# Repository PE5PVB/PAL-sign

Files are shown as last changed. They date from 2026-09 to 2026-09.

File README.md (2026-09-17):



# PAL-sign
Advanced CVBS PAL test card generator, built around an RP2350 and an ADV7391 video encoder

A standalone hardware test card generator for anyone working with analogue television: an ATV contest, aligning a transmitter or receiver, or just needing a proper PAL B/G composite signal on the bench. Twenty broadcast-standard test cards, generated in real time and sent out as CVBS, no PC required to run it.

## Features
- Twenty built-in test cards: PM5644 (4:3 and 16:9), BBC Cards F/G/W, FuBK (full, simple and 16:9), EBU colour bars and black & white, Crosshatch, Multiburst, Pulse & Bar, sin(x)/x, Mixed bars, Picdream, an ATV Contest card and a TVE card
- Fourteen Custom slots for your own pictures, uploaded from the PC tool
- BBC Test Card F and W can each show a photo of your own instead of the original, centred and uploaded from the PC tool
- Teletext, WSS aspect ratio signalling and Insertion Test Signal (ITS) support
- A slideshow with a fade between pictures
- A scrolling ticker band, colour, speed and size configurable per card
- An on-device menu on its own screen, driven by a rotary encoder, so every setting is reachable without a PC
- Optional PCM audio: with a PCM1808 ADC attached, two extra cards embed stereo sound in the picture itself (see "PCM audio" below)
- A Windows configurator to upload your own pictures and change every setting from a PC

## Controls and settings
Everything below is reachable from the on-device screen and knob, or from the PC tool; the two show the same settings.

### The screen and the knob
A small screen and a rotary encoder on the front, entirely optional: unplug that panel and the firmware skips it and keeps generating video (a pin on the flatcable tells it whether the panel is there). Turning the knob steps through the list of cards without touching what is on air; pushing switches to the highlighted one.
- A short press opens a menu for the card currently shown, with everything specific to that one card.
- A press held for about two seconds opens the System menu instead, with everything that is not tied to one card.
- The menu closes itself after a minute of no input.
- Holding the knob down while powering the board on starts a five-second on-screen countdown; holding through the whole countdown runs a full factory reset (every setting back to its default) once it finishes, releasing early cancels it.

### The per-card menu (short press)
What is offered depends on the card: one with no room for a ticker will not offer one, and one with no clock box will not offer a colour for it. Between them, the twenty cards can offer:
- Enabled: whether stepping through the cards can land on this one; a disabled card keeps its settings, it is just skipped
- Ticker: off, solid or transparent (transparent only on a built-in card, an uploaded photo has no room budget for it), its vertical position, speed and direction, one of five sizes and four fonts, and its colour
- Aspect ratio: nine WSS modes, off, 4:3 full frame, 14:9 letterbox (centred or at the top), 14:9 full frame, 16:9 letterbox (centred or at the top), 16:9 anamorphic, and a wider-than-16:9 letterbox, switching the ADV7391's own wide screen signalling to match
- The first and second identification lines: shown or hidden, and their own colour
- The moving line, on the cards that have one
- The insert boxes (a running clock, or fixed text instead): off, time only, date and time, or the fixed text
- The text font used for all of the above
- A handful of card-specific extras: the PM5644 16:9's chroma test bars, Test Card G's AP2 variant, the ATV Contest card's two lines and contest number, and BBC Test Card F/W's own switch for a custom photo instead of the original

### The System menu (long press)
- Text: the first and second identification line, the ticker message, and the fixed text an insert box shows instead of a running clock
- Switches: teletext, ITS (Insertion Test Signal), VBI, and automatic summer time
- Two cycles: the ADV7391's luma and chroma filter presets
- The screen's own brightness
- The date and time, set field by field, kept automatically in step with summer time if that switch is on
- Enabling or disabling any of the twenty cards, without touching what is currently on air
- Seven analogue controls on the ADV7391 itself: DAC gain, Y scale, brightness, hue, the luma peaking filter (SSAF), and the luma and chroma delay

### The slideshow
A sequence of steps, each "how long, which card", built by dragging cards into an order in the PC tool. Any card can appear more than once, each occurrence with its own duration, and there is an optional fade between pictures. The sequence is stored in its own flash page and survives a power cycle, so a slideshow left running keeps running after a restart.

### The ticker
A scrolling text band that can run on almost any card, configured per card as listed above: on or off, or transparent over the picture instead of a solid band; where it sits, how fast and in which direction it scrolls; one of five sizes, one of four fonts, and its own colour. The message itself is shared across every card that shows it.

### Your own photo on BBC Test Card F and W
Both cards have their own oval photo window built in; the PC tool's "Upload portrait..." button lets you put your own picture there instead. The two windows are not quite the same size or shape, so one upload feeds both: choose a photo, drag it and use the zoom slider until the right part sits inside both outlines shown on the preview, and both are cut out and sent in one step. Each card keeps its own on/off switch (see the per-card menu above), so you can show your photo on one, the original on the other, or either everywhere.

## Test cards
Six of the twenty, captured straight off the composite output.

<table>
<tr>
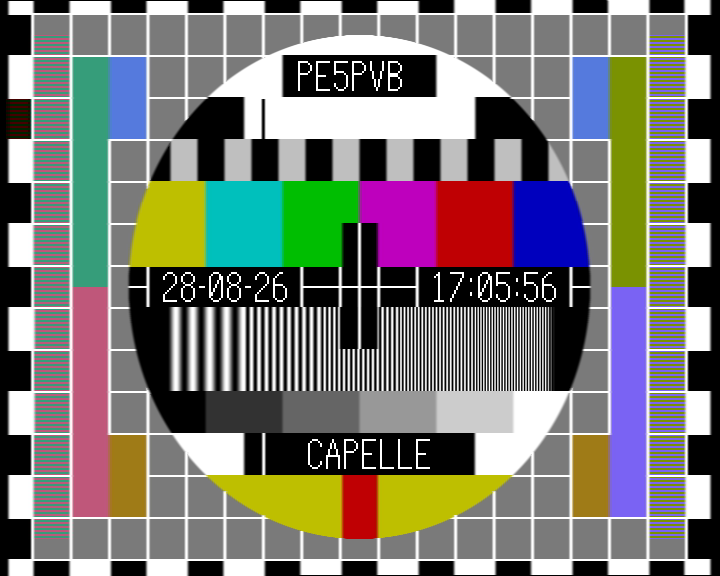
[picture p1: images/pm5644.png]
PM5644
<td width="33%"><br><b>PM5644</b><br>The classic Philips PM5644, straight from the original EPROM dump: colour bars, a resolution grating in each corner, a grey scale and the two identification boxes, "PE5PVB" and "CAPELLE" here, with the on-device clock in the middle.</td>
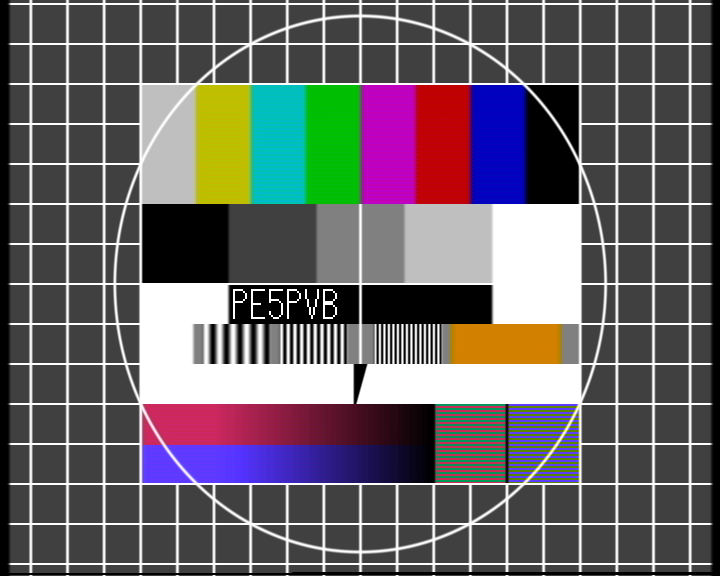
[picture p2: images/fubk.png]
FuBK
<td width="33%"><br><b>FuBK</b><br>FuBK, the German counterpart of the PM5544, taken from an actual composite recording. The two striped fields right of the gradient bars deliberately mis-modulate the colour signal; a properly working PAL decoder averages them down to plain grey.</td>
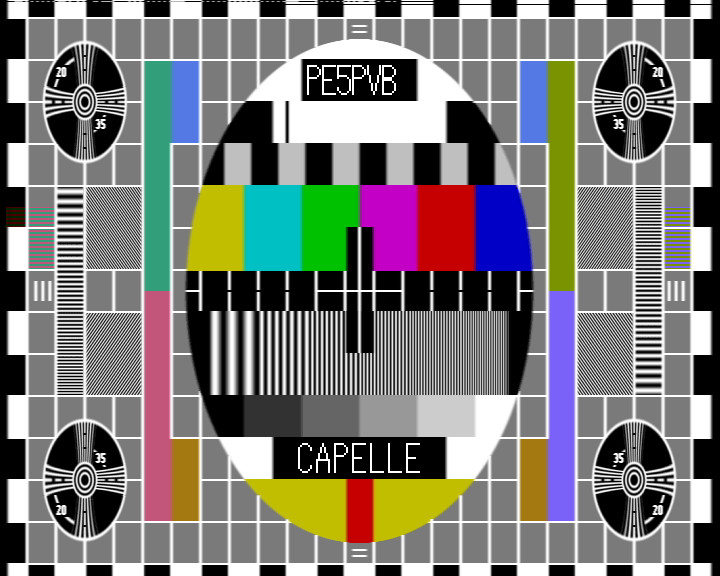
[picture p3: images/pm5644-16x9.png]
PM5644 16:9
<td width="33%"><br><b>PM5644 16:9</b><br>The same PM5644 picture from a newer generation of the encoder EPROM (G924): finer detail and the identification boxes in slightly different places than the plain PM5644.</td>
</tr>
<tr>
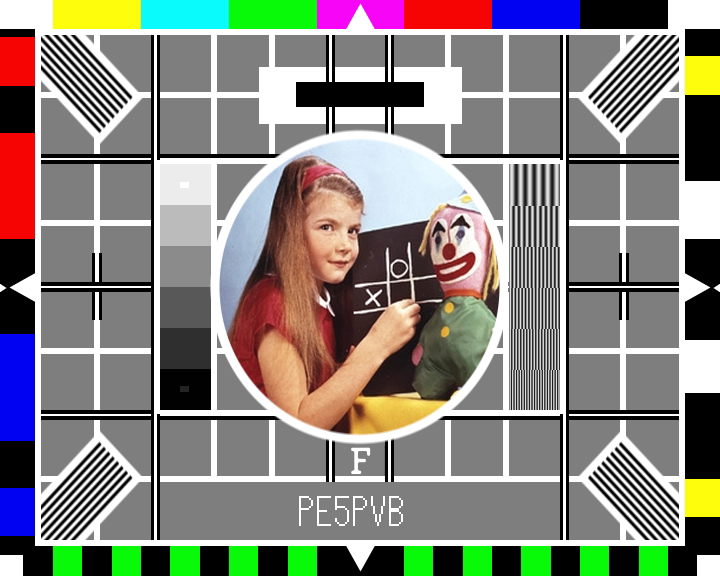
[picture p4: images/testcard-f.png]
BBC Test Card F
<td width="33%"><br><b>BBC Test Card F</b><br>The well known girl-and-clown card, rebuilt from the original photo scan, surrounded by colour bars, resolution wedges and a grey scale.</td>
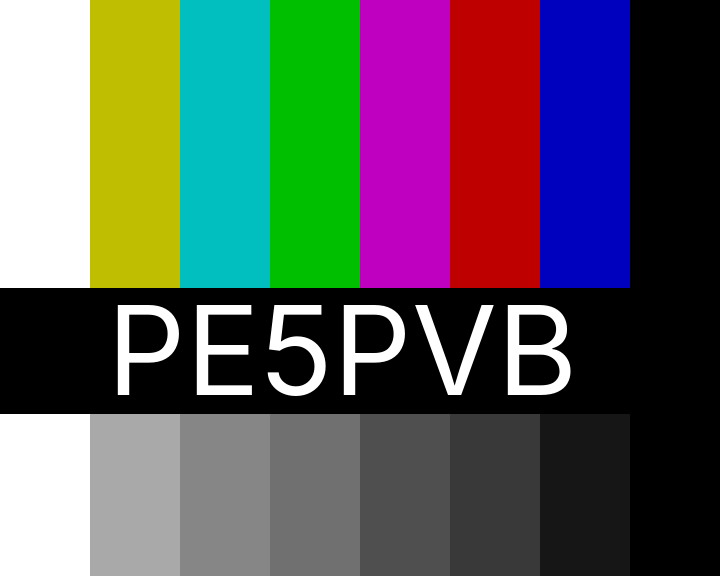
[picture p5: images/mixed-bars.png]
Mixed bars
<td width="33%"><br><b>Mixed bars</b><br>The same eight colour bars twice: once in colour, once with the chroma stripped out, so the bottom row shows exactly the brightness each colour bar carries.</td>
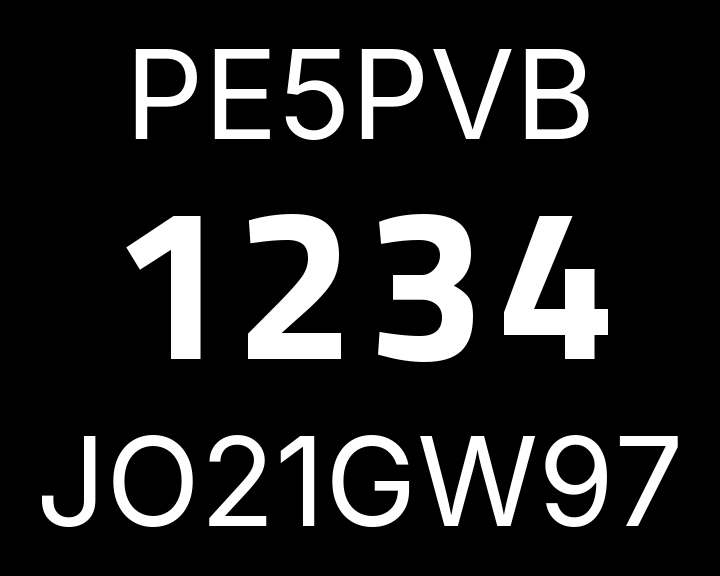
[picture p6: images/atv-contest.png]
ATV Contest
<td width="33%"><br><b>ATV Contest</b><br>Callsign, contest number and locator in large, legible digits, meant to be read off a weak or noisy signal during a contest.</td>
</tr>
</table>

## How it works

### From pixels to composite video
The RP2350 does not generate the analogue PAL signal itself. Its PIO hardware (a handful of small, exactly timed state machines built into the chip for jobs like this) pushes the picture out as a digital YCbCr 4:2:2 byte stream on an 8 bit bus, together with a 27 MHz clock, following the BT.656 standard. That digital stream, plus a couple of control pins, goes straight into an Analog Devices ADV7391 video encoder over I2C for configuration. The ADV7391 does the actual PAL encoding: it generates the colour subcarrier, mixes in luma and chroma, adds the analogue sync pulses and drives the composite (CVBS) output.

### No separate sync wires
An older-style video source uses two extra wires next to the picture data, HSYNC and VSYNC, to mark the start of every line and every field. BT.656 does not need them: it puts special byte codes (SAV and EAV, values that never occur in real picture data) straight into the byte stream itself, at the start and end of every active line. The ADV7391 reads its own timing out of those codes, so on this board HSYNC and VSYNC are simply wired high and never toggle.

### Keeping the two cores in step
One RP2350 core works out the pixel data for the current picture, line by line, and writes it into a ring buffer. The other core only reads that buffer back out to the PIO/DMA hardware, at a fixed pace, so the picture can never fall behind: DMA moves the bytes from the buffer into the PIO's FIFO without either core handling them one by one. If the rendering core ever gets too far behind, for instance during a picture switch, the firmware notices and falls back to repeating the last complete picture instead of letting anything incomplete reach the screen.

### Teletext, WSS and the other things hidden in the picture
Teletext, the widescreen signalling (WSS) and the insertion test signal (ITS) are not produced by a separate chip. They are ordinary picture data: a handful of lines in the vertical blanking interval, the lines you never actually see, above and below the visible picture, get filled with luma samples that decode into the teletext bits or the WSS code, exactly like any other line of picture content decodes into a colour. The firmware works out that waveform itself, pulse by pulse, to the shape the relevant standard requires, and writes it straight into the same buffer the ADV7391 streams out.

### Test cards and your own pictures
The twenty built-in test cards are pixel data compiled straight into the firmware; several of them, the PM5644 and BBC cards, come from the original EPROM dumps of real broadcast test card generators. Alongside those sit fourteen Custom slots: plain picture data reserved in the last part of the 16 MB flash chip, which you fill from the PC tool over the same USB serial connection used for firmware uploads.

### The screen and the knob
The screen on the front is a plain SPI display, and the knob next to it is an ordinary quadrature rotary encoder, decoded from a GPIO interrupt so a fast turn is never missed; see "Controls and settings" above for what they do.

## Connecting the screen and the knob
The screen and the rotary encoder live on their own small front panel PCB, connected with a flatcable, and the whole panel is optional: one pin on the cable tells the firmware whether it is there, and without it the board runs headless and keeps generating video.

The display is an **ST7789P3** SPI panel of **76 x 284 pixels** (a window inside the controller's 240 x 320 frame memory), driven over SPI0. The knob is an ordinary quadrature rotary encoder with a push switch; the RP2350's internal pull-ups do the rest, so the panel needs no resistors or capacitors of its own.

| Signal | GPIO | Notes |
|---|---|---|
| Display RST | GP19 | |
| Display CS | GP20 | |
| Display DC | GP21 | low = command |
| Display SCK | GP22 | SPI0 SCK |
| Display MOSI (SDA) | GP23 | SPI0 TX |
| Display backlight | GP26 | active high |
| Panel present | GP24 | tie to GND on the panel |
| Encoder phase A | GP27 | internal pull-up |
| Encoder phase B | GP28 | internal pull-up |
| Encoder push | GP29 | internal pull-up |

Plus 3.3 V and GND for the panel itself. The encoder's common and the switch's other side go to GND.

## PCM audio
An optional PCM1808 audio ADC turns the generator into a video-plus-audio source: the analogue stereo input is sampled at 48 kHz and embedded in the picture itself as data lines, in the spirit of the PCM adaptors of the early digital audio era. Two extra cards carry it:

- **Ham PCM**: an own format designed for FM ATV links, with Reed-Solomon error protection, a small text channel, and four quality modes: HQ (48 kHz, 14 bit stereo), LQ (32 kHz, 12 bit stereo), Voice (32 kHz A-law) and Narrow (16 kHz mono A-law).
- **Sony PCM**: a Sony/EIAJ STC-007-compatible signal (44.1 kHz, 14 or 16 bit, selectable pre-emphasis) that period PCM adaptors and third-party software decoders understand.

Both cards appear automatically when the ADC is detected at power-on, and stay completely hidden without it, on the board, in the menu and in the PC tool alike. The `PcmDecoder` tool in `PC Software/` plays the audio back on a PC from a composite capture card, with a live view of the decode quality.

The ADC connects over I2S, with the PCM1808 in master mode: the board supplies only the 12.288 MHz system clock, and the ADC generates its own bit and word clocks from it.

| Signal | GPIO | Direction |
|---|---|---|
| SCKI (256 fs master clock) | GP13 | board to ADC |
| BCK (bit clock) | GP9 | ADC to board |
| LRCK (word clock) | GP10 | ADC to board |
| DOUT (I2S data) | GP11 | ADC to board |

Plus supply and GND for the ADC board. The PCM1808's mode pins go high for master mode (MD1 = MD0 = high).

## Repository layout
- `Firmware/` -- the firmware for the RP2350, built with PlatformIO or the Arduino IDE
- `PC Software/` -- the Windows configurator, see [its own README](PC%20Software/README.md) for how to build and use it
- `Hardware/Kicad/` -- the PCB design

## Building the firmware
```
cd Firmware
pio run
pio run -t upload
```
PlatformIO picks up everything it needs from `platformio.ini`, including the board profile for the bare RP2350. Opening `Firmware.ino` in the Arduino IDE (2.x) works as well; `sketch.yaml` carries the same board settings.

## Contributing
Found a bug or have an idea? Open an [issue](https://github.com/PE5PVB/PAL-sign/issues) or a [pull request](https://github.com/PE5PVB/PAL-sign/pulls), I will review it and merge into main. Since this project is dual-licensed (see below), a pull request means you agree that your contribution is licensed the same way as the rest of the project, under both the GPLv3 and the commercial license.

## License
This project is dual-licensed.

You may use it under the terms of the GNU General Public License, either version 3 of the License, or (at your option) any later version: this program is free software, you can redistribute it and/or modify it under those terms. It is distributed in the hope that it will be useful, but WITHOUT ANY WARRANTY; without even the implied warranty of MERCHANTABILITY or FITNESS FOR A PARTICULAR PURPOSE. See the [LICENSE](LICENSE) file for the full text.

If the GPLv3's terms do not suit your use, for example because you want to use this project, or a part of it, in a closed-source or commercial product without releasing your own source code, a separate commercial license is available. See [pe5pvb.nl](https://www.pe5pvb.nl/) for contact details.

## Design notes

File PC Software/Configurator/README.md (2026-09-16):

# PAL-sign, the configurator

Windows program that goes with the test card generator. Its sibling
`../PCMDecoder` (same folder layout) turns a captured Ham PCM or Sony
PCM picture back into sound; `../PAL-sign.sln` opens both projects in
Visual Studio 2022 or newer. From the command line:

```
dotnet run --project src/PAL-sign.csproj
```

A standalone .exe (needs the .NET 8 Desktop runtime) is built by
`publish.bat`. Use that script rather than a hand written
`dotnet publish`: the options interact in a way that is easy to get wrong
on the command line.

C# on .NET 8 (LTS) with WinForms, three tab pages: Cards (every per-card
setting, including converting a photo and sending it to one of the
fourteen Custom slots, or a photo of your own onto BBC Test Card F/W's
own oval window), Slideshow, and System (everything that is not tied to
one card).

## The risk of this program, and how it is covered

This is the **second implementation** of the image conversion. The first
is in `../../Firmware/tools/convert_image.py` and is the one proven to work
on the board. Two implementations drift apart sooner or later, and then a
difference on the screen can no longer be traced back to one cause.

That is why it has been made measurable instead of hoped for:

```
python compare.py
```

That runs both implementations on the same input and lays the output side
by side byte for byte, in two trials with a different purpose:

**A. The arithmetic.** Input that is already 720x576, so nothing is
scaled. What is left is the YCbCr conversion, the flicker filter, the
chroma halving and the level limiting. That ought to be equal byte for
byte, and it is, at flicker filter 0.00, 0.50 and 1.00. If this differs,
there is a real fault.

**B. The scaling.** No equality is expected here: PIL works out its
Lanczos weights in fixed point and rounds per pass to 8 bits, the C#
version works in double. What the trial reports is the size of the
difference, so that you can tell rounding noise from something else.

That second trial paid for itself immediately. It found that
`DrawImageUnscaled` from GDI+ scales to the **physical** size and not
pixel for pixel: a JPEG of 72 dpi was enlarged by 96/72 before the tool's
own Lanczos had even started, which is not recognisable as a fault by
eye. See the explanation in `src/ImageReader.cs`.

**Before either trial**, `compare.py` checks `ImageConvert.AlgoVersion`
(read straight from the built exe, `PAL-sign.exe --algo-version`)
against `ALGO_VERSION` in `convert_image.py`, and stops right there if
they differ. A byte-for-byte pass in trial A only proves the two are
still the same algorithm if this matched first: without it, a change on
one side that happens to still pass on whatever input trial A used that
day would go unnoticed. Whoever changes the pixel arithmetic on either
side bumps both constants, in the same commit, once trial A passes
again.

## Checking the layout

```
src/bin/Debug/net8.0-windows/PAL-sign.exe --layout layout.txt
```

Builds the window off screen, lets it lay itself out, and writes down
where every element ends up. It reports two things you spot too late by
eye: elements that **overlap each other** and elements that fall
**outside their parent**. Exit code 0 means clean.

With WinForms the order of `Controls.Add` determines who takes precedence
when docking, and an element set to `Fill` that is added **first** claims
the whole client area, leaving the rest to end up on top of it. That is
why everything now sits in a `TableLayoutPanel`.

## What the settings do

| | |
|---|---|
| **To** | which of the fourteen uploadable Custom slots you overwrite |
| **Crop** | fill the picture instead of black bars |
| **Force square-pixel scaling on an exact 720x576 source** | scale it anyway, instead of passing it through as already PAL-shaped |
| **Flicker filter** | takes the interlace twitter out; see below |

### Flicker filter

Even image rows go to field 1 and odd ones to field 2. Anything that
changes sign from row to row, a roof edge, a striped shirt, a horizontal
branch, therefore sits differently in one field than in the other, and
you see that as flicker at 25 Hz.

The kernel `[1,2,1]/4` is derived and not chosen: it is exactly the
filter that sets that alternating component to zero. See `AntiTwitter()`
in `src/ImageConvert.cs` and `anti_twitter()` in `convert_image.py`.

At 1.00 the twitter is fully gone. It costs vertical sharpness, because
the twittering component is vertical detail; at 0.50 you leave half of it
standing.

## The preview

What you see is not the bare 720x576 raster but the picture **stretched
to 4:3**, because that is how it arrives on the television. It is also
worked back out of the actual 4:2:2 bytes, so you see what the chroma
halving and the level limiting make of it as well.

## During the upload

**No picture** comes out of the board while it is writing. The board does
**not** restart and the port simply stays open: the streamer on the other
core runs from RAM and keeps sending blank lines with correct sync. The
explanation is at `photoUpload()` in `../../Firmware/src/main.cpp`.

At the end the firmware reports the CRC it has read back out of the
**flash**, and the configurator compares that with its own calculation.
If it says "CRC agrees", then it really is in there correctly.

## The command line remains

`../../Firmware/tools/convert_image.py` still does the same thing and is the
reference that `compare.py` measures against. There was also a tkinter
window; that lapsed when this program arrived.

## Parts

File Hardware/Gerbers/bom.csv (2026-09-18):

Designator | Footprint | Quantity | Value | LCSC Part #
BT1 | CR2032-BS-6-1 | 1 | ML2032 | C70377
C1, C2, C5, C6, C9 | 0603 | 5 | 4.7uF | C19666
C10, C12, C13, C14, C15, C16, C17, C18, C19, C20, C21, C22, C25, C28, C32, C34, C35, C37, C39, C42, C44, C45, C47, C7, C8 | 0603 | 25 | 100n | C14663
C11 | 0603 | 1 | 4n7 | C53987
C23, C38, C43, C46 | 0603 | 4 | 10uF | C96446
C24, C27 | 0603 | 2 | 10n | C57112
C26 | 0603 | 1 | 2.2nF | C1604
C29 | 0603 | 1 | 150n | C513735
C3, C4 | 0603 | 2 | 15p | C1644
C30 | 0603 | 1 | 12n | C107074
C31, C33, C36 | CP_Elec_8x10 | 3 | 470uF | C48970894
C40, C41 | 0805 | 2 | 22uF | C45783
D1, D6 | D_SOD-123 | 2 | B5819W | C8598
D2 | 0603 | 1 | ACT | C2286
D3, D4, D5 | 0603 | 3 | CG0603MLC-05LE | C2655331
FB1, FB5 | 0603 | 2 | BLM18HG601SN1D | C85830
FB2, FB3, FB4 | 0603 | 3 | BLM18PG331SN1D | C79913
J1 | 12402012E212A | 1 | 12402012E212A | C5150972
J2 | PinHeader_2x04_P2.54mm_Vertical | 1 | I2S | C5156676
J3 | PinHeader_2x06_P2.54mm_Vertical | 1 | FRONT | C5224012
J4 | RF1-01A-D-00-75-M | 1 | VIDEO1 | C5454776
J5 | RF1-01A-D-00-75-M | 1 | VIDEO2 | C5454776
J6 | RF1-01A-D-00-75-M | 1 | VIDEO3 | C5454776
J7 | BarrelJack_GCT_DCJ200-10-A_Horizontal | 1 | Barrel_Jack_Switch | C16214
L1 | 0806 | 1 | 3.3uH | C42411119
L2 | FIL_ACM2012-900-2P-T002 | 1 | ACM2012-201-2P-T001 | C383338
L3, L4 | 1008 | 2 | 2.2uH | C576403
R1, R16, R18 | 0603 | 3 | 10k | C25804
R10, R11, R12, R13, R9 | 0603 | 5 | 5k1 | C23162
R14 | 0603 | 1 | 4k12 | C863836
R15 | 0603 | 1 | 300 | C23025
R17 | 0603 | 1 | 150 | C22808
R19 | 0603 | 1 | 20 | C22950
R2 | 0603 | 1 | 33 | C23140
R20, R21, R22 | 0603 | 3 | 75 | C4275
R23 | 0603 | 1 | 1M1 | C2930138
R24 | 0603 | 1 | 210k | C22952
R3, R4 | 0603 | 2 | 1k | C21190
R5, R6 | 0603 | 2 | 27.4 | C177713
R7 | 0603 | 1 | 1M | C22935
R8 | 0603 | 1 | 2k2 | C4190
SW1 | SW_SPST_B3U-1000P | 1 | BOOT | C231329
U1 | SOIC-8_5.3x5.3mm_P1.27mm | 1 | W25Q128JVS | C97521
U2 | SOT-666 | 1 | USBLC6-2P6 | C15999
U3 | QFN-60-1EP_7x7mm_P0.4mm_EP3.4x3.4mm | 1 | RP2350A | C42411118
U4 | LFCSP-32-1EP_5x5mm_P0.5mm_EP3.1x3.1mm | 1 | ADV7391BCPZ | C662283
U5 | MicroCrystal_C7_SON-8_1.5x3.2mm_P0.9mm | 1 | RV-3028-C7 | C3304278
U6 | SOIC-8_3.9x4.9mm_P1.27mm | 1 | THS7314 | C882751
U7 | Texas_DSG0008A_WSON-8-1EP_2x2mm_P0.5mm_EP0.9x1.6mm_ThermalVias | 1 | TPS62160DSG | C324077
U8 | SOT-23-5 | 1 | TPS7A2033PDBVR | C2862740
U9 | SOT-23-5 | 1 | TPS7A2018PDBVR | C963430
Y1 | Crystal_SMD_3225-4Pin_3.2x2.5mm | 1 | ABM8-272-T3 | C20625731

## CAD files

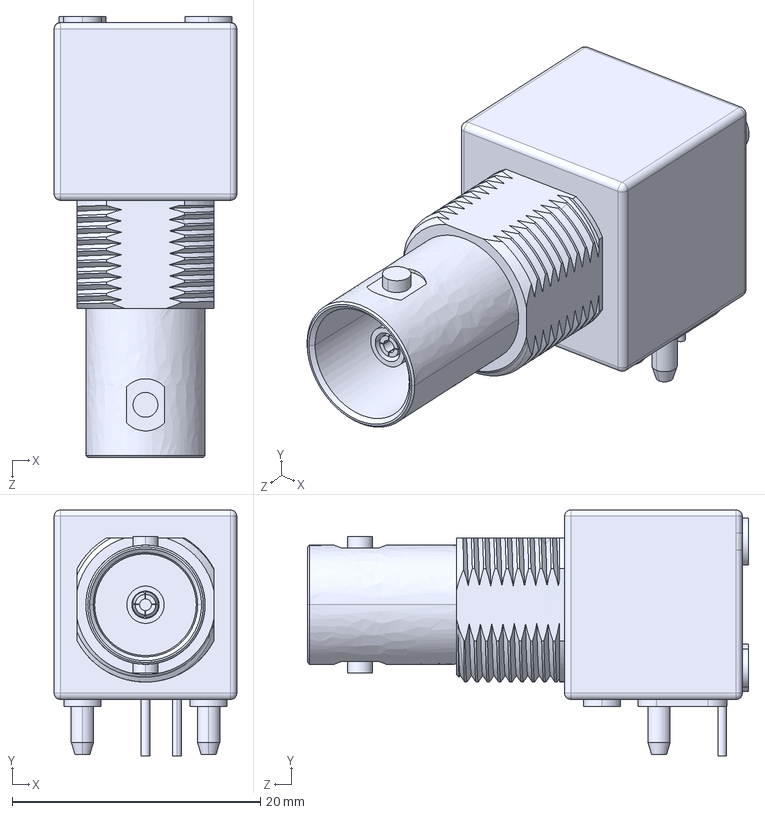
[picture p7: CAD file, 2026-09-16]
Hardware/Kicad/3d/rf1-01a-d-00-75-m-model.step
14.7 x 19.8 x 35.5 mm

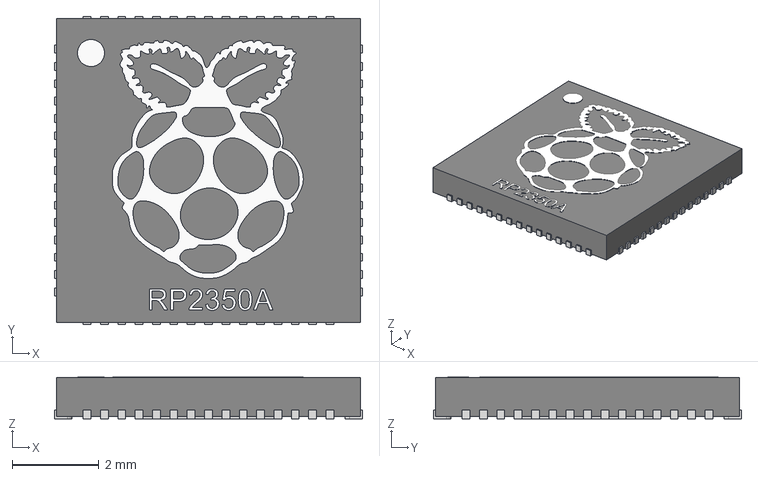
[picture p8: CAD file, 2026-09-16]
Hardware/Kicad/3d/RP2350A.stp
7.10 x 7.10 x 0.96 mm

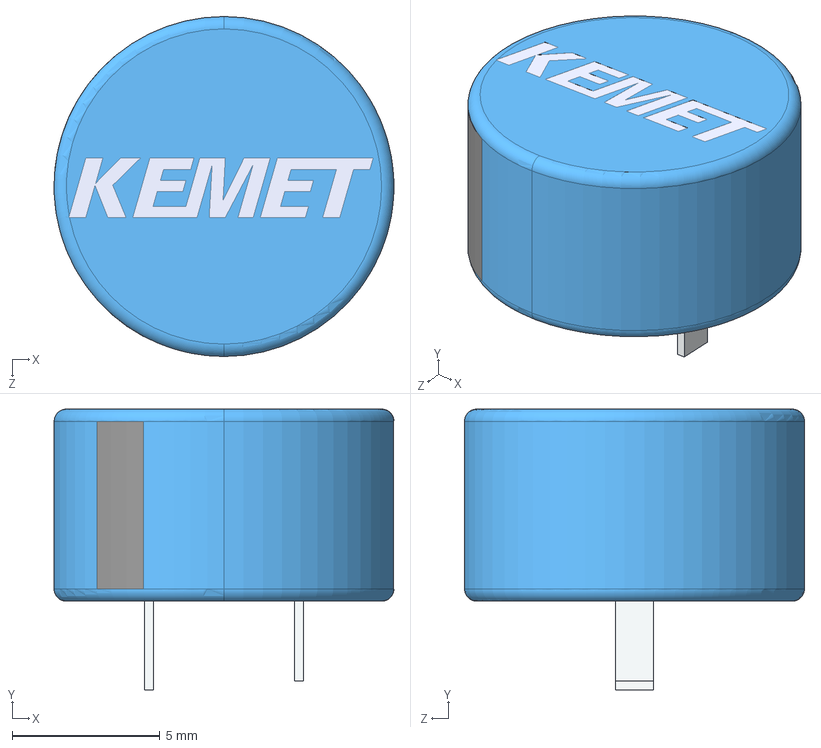
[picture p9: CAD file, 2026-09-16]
Hardware/Kicad/3d/FG0H104ZF.step
11.5 x 9.50 x 11.5 mm

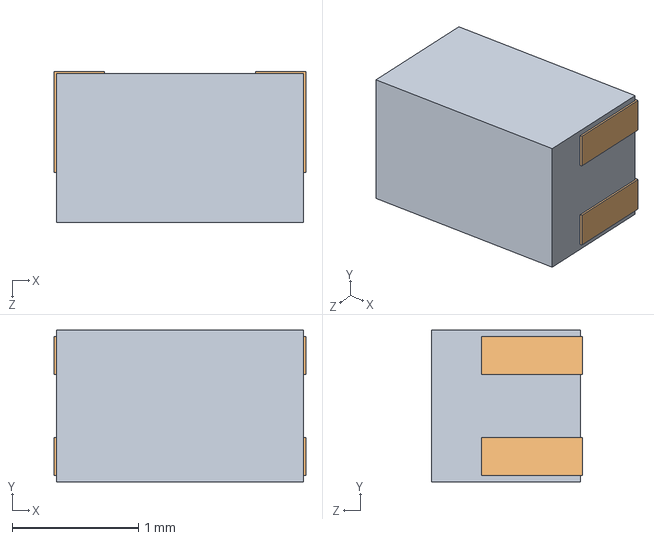
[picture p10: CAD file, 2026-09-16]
Hardware/Kicad/3d/acm2012-t001.step
2.00 x 1.20 x 1.20 mm
ACM2012-T001 DRコアブロック(typ size)
ACM2012-T001 電極ブロック(typ size) x 2

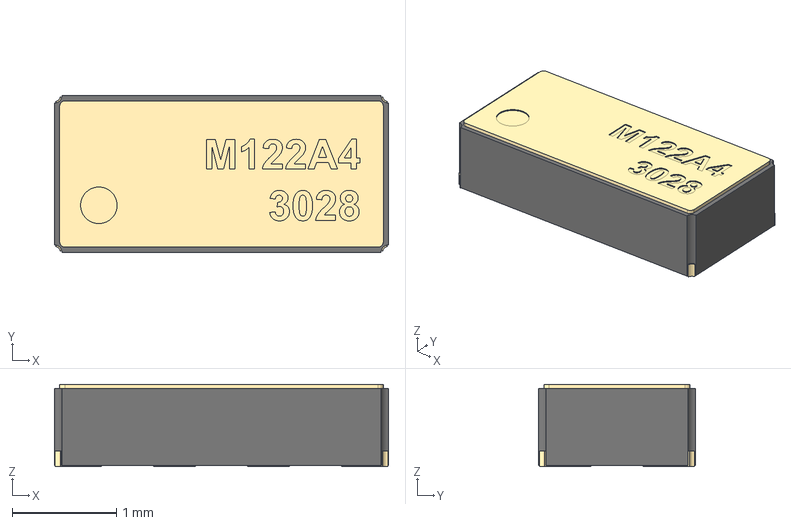
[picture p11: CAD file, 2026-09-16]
Hardware/Kicad/3d/RV-3028-C7.step
3.20 x 1.50 x 0.79 mm
Rect2
Rect3
Rect4
Rect5
Terminal

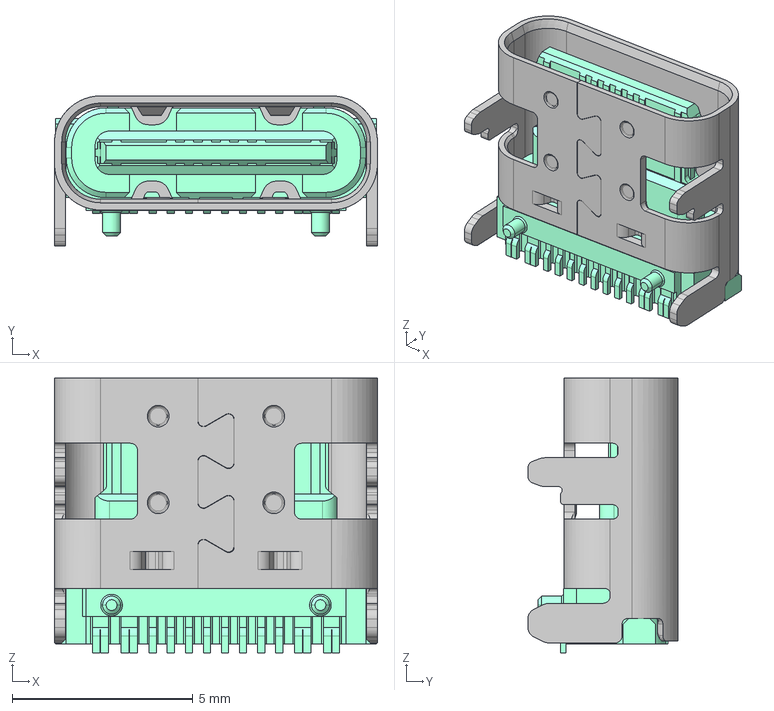
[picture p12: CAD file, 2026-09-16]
Hardware/Kicad/3d/C12402012-3.stp
8.94 x 4.16 x 7.60 mm

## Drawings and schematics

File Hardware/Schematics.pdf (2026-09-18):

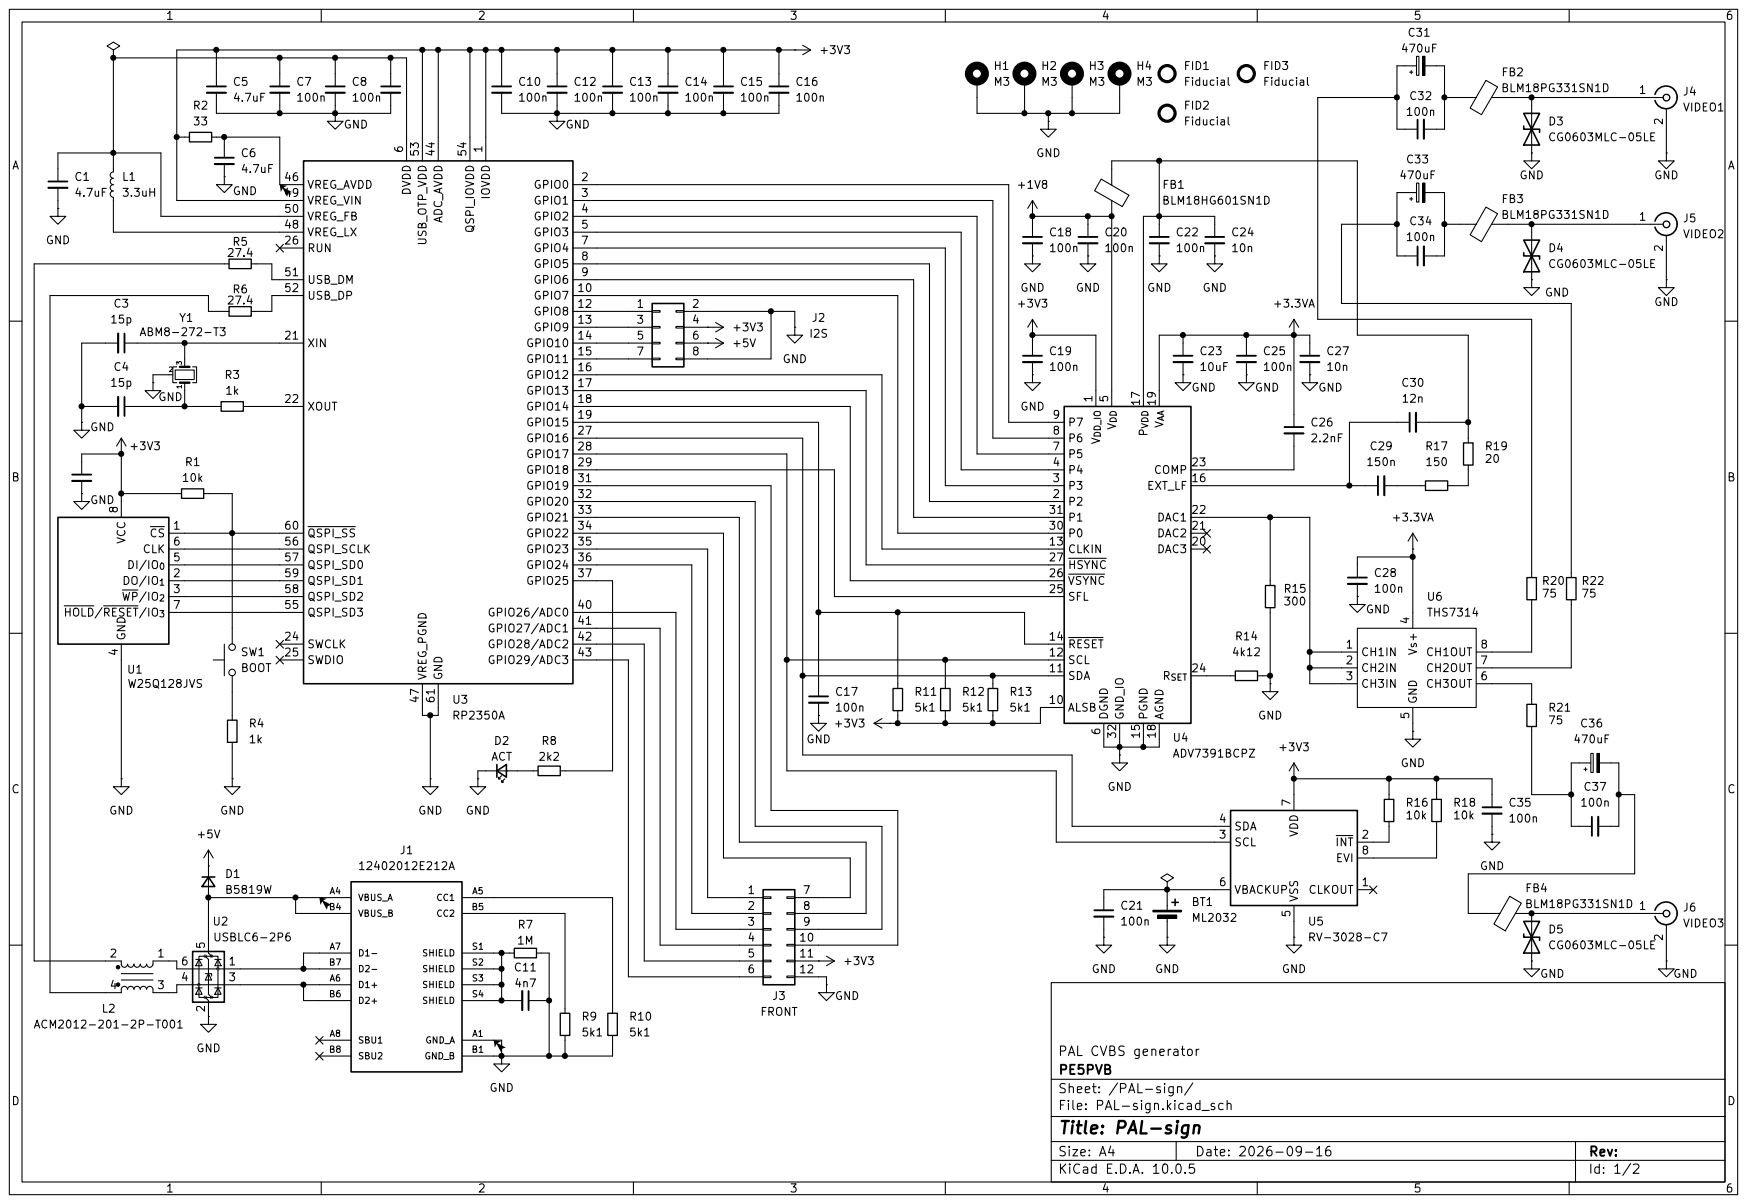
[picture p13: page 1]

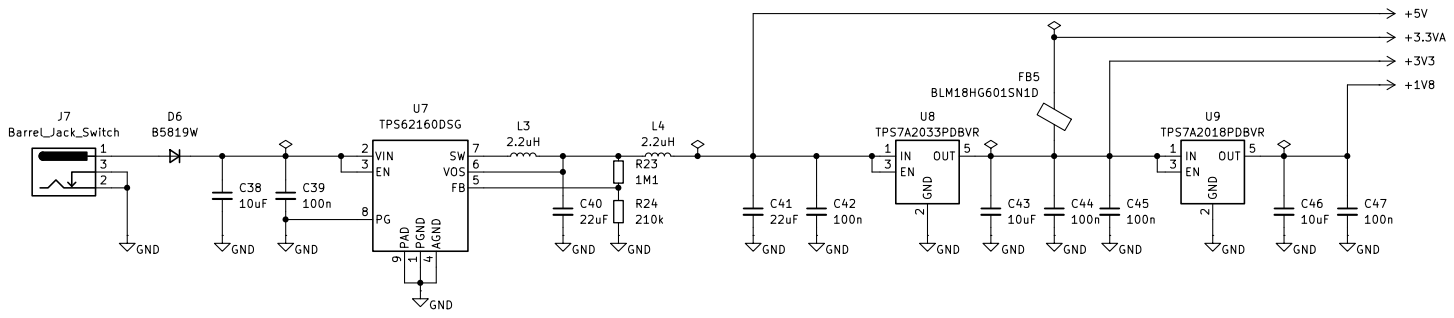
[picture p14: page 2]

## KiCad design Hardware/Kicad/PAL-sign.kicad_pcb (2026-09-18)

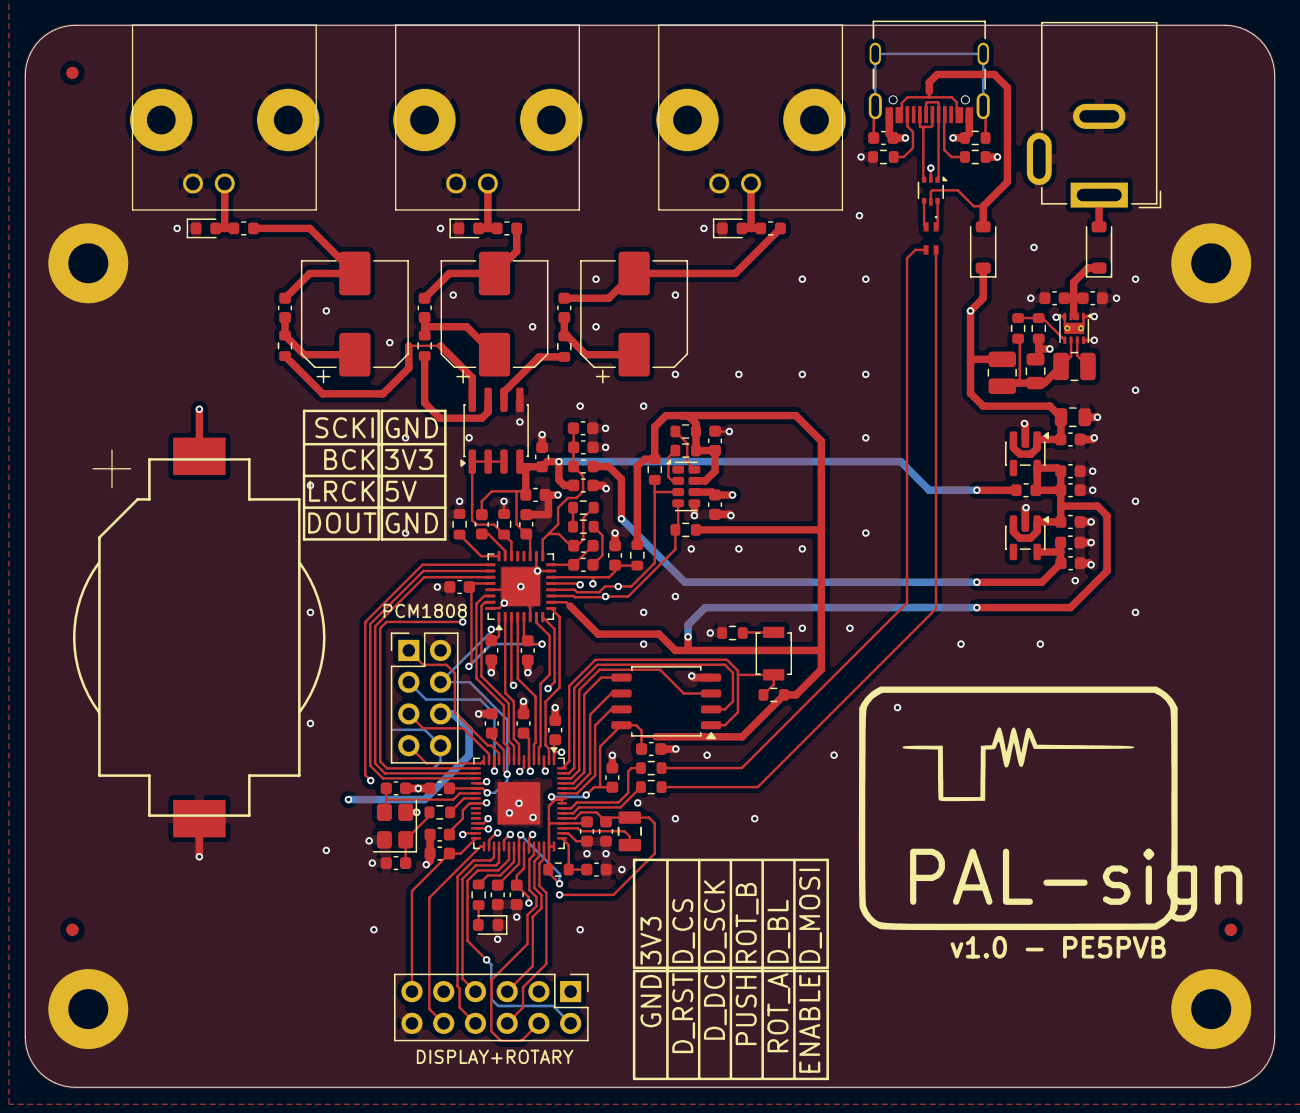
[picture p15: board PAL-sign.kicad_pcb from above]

Board: 4 copper layers, 100.0 x 85.0 mm, 112 parts (0 on the bottom side), 88 nets.

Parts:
BT1: ML2032; CR2032-BS-6-1
C1, C2, C5, C6, C9: 4.7uF; C_0603_1608Metric
C3, C4: 15p; C_0603_1608Metric
C7, C8, C10, C12, C13, C14, C15, C16, C17, C18, C19, C20, C21, C22, C25, C28, C32, C34, C35, C37, C39, C42, C44, C45, C47: 100n; C_0603_1608Metric
C11: 4n7; C_0603_1608Metric
C23, C38, C43, C46: 10uF; C_0603_1608Metric
C24, C27: 10n; C_0603_1608Metric
C26: 2.2nF; C_0603_1608Metric
C29: 150n; C_0603_1608Metric
C30: 12n; C_0603_1608Metric
C31, C33, C36: 470uF; CP_Elec_8x10
C40, C41: 22uF; C_0805_2012Metric
D1, D6: B5819W; D_SOD-123
D2: ACT; LED_0603_1608Metric
D3, D4, D5: CG0603MLC-05LE; D_0603_1608Metric
FB1, FB5: BLM18HG601SN1D; L_0603_1608Metric
FB2, FB3, FB4: BLM18PG331SN1D; L_0603_1608Metric
FID1, FID2, FID3: Fiducial; Fiducial_1mm_Mask2mm
H1, H2, H3, H4: M3; MountingHole_3.2mm_M3_Pad
J1: 12402012E212A
J2: I2S; PinHeader_2x04_P2.54mm_Vertical
J3: FRONT; PinHeader_2x06_P2.54mm_Vertical
J4: VIDEO1; RF1-01A-D-00-75-M
J5: VIDEO2; RF1-01A-D-00-75-M
J6: VIDEO3; RF1-01A-D-00-75-M
J7: Barrel_Jack_Switch; BarrelJack_GCT_DCJ200-10-A_Horizontal
L1: 3.3uH; L_0806_2016Metric
L2: ACM2012-201-2P-T001; FIL_ACM2012-900-2P-T002
L3, L4: 2.2uH; L_1008_2520Metric
R1, R16, R18: 10k; R_0603_1608Metric
R2: 33; R_0603_1608Metric
R3, R4: 1k; R_0603_1608Metric
R5, R6: 27.4; R_0603_1608Metric
R7: 1M; R_0603_1608Metric
R8: 2k2; R_0603_1608Metric
R9, R10, R11, R12, R13: 5k1; R_0603_1608Metric
R14: 4k12; R_0603_1608Metric
R15: 300; R_0603_1608Metric
R17: 150; R_0603_1608Metric
R19: 20; R_0603_1608Metric
R20, R21, R22: 75; R_0603_1608Metric
R23: 1M1; R_0603_1608Metric
R24: 210k; R_0603_1608Metric
SW1: BOOT; SW_SPST_B3U-1000P
U1: W25Q128JVS; SOIC-8_5.3x5.3mm_P1.27mm
U2: USBLC6-2P6; SOT-666
U3: RP2350A; QFN-60-1EP_7x7mm_P0.4mm_EP3.4x3.4mm
U4: ADV7391BCPZ; LFCSP-32-1EP_5x5mm_P0.5mm_EP3.1x3.1mm
U5: RV-3028-C7; MicroCrystal_C7_SON-8_1.5x3.2mm_P0.9mm
U6: THS7314; SOIC-8_3.9x4.9mm_P1.27mm
U7: TPS62160DSG; Texas_DSG0008A_WSON-8-1EP_2x2mm_P0.5mm_EP0.9x1.6mm_ThermalV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
U8: TPS7A2033PDBVR; SOT-23-5
U9: TPS7A2018PDBVR; SOT-23-5
Y1: ABM8-272-T3; Crystal_SMD_3225-4Pin_3.2x2.5mm

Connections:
+1V8: C18.1, C20.1, C46.1, C47.1, FB1.1, U4.5 (V_{DD}), U4.28 (V_{DD}), U9.5 (OUT)
+3.3VA: C23.1, C25.1, C26.1, C27.1, C28.1, FB5.2, U4.19 (V_{AA}), U6.4 (Vs+)
+3V3: C2.1, C5.1, C10.1, C12.1, C13.1, C14.1, C15.1, C16.1, C19.1, C35.1, C43.1, C44.1, C45.1, FB5.1, J2.4, J3.11, R1.1, R2.1, R11.2, R12.2, R13.2, R16.1, R18.1, U1.8 (VCC), U3.1 (IOVDD), U3.11 (IOVDD), U3.20 (IOVDD), U3.30 (IOVDD), U3.38 (IOVDD), U3.44 (ADC_AVDD), U3.45 (IOVDD), U3.49 (VREG_VIN), U3.53 (USB_OTP_VDD), U3.54 (QSPI_IOVDD), U4.1 (V_{DD_IO}), U4.10 (ALSB), U5.7 (VDD), U8.5 (OUT), U9.1 (IN), U9.3 (EN)
+5V: C41.1, C42.1, D1.1 (K), J2.6, L4.2, U8.1 (IN), U8.3 (EN)
GND: BT1.2 (-), C1.2, C2.2, C3.2, C4.2, C5.2, C6.2, C7.2, C8.2, C9.2, C10.2, C11.1, C12.2, C13.2, C14.2, C15.2, C16.2, C17.2, C18.2, C19.2, C20.2, C21.2, C22.2, C23.2, C24.2, C25.2, C27.2, C28.2, C35.2, C38.2, C39.2, C40.2, C41.2, C42.2, C43.2, C44.2, C45.2, C46.2, C47.2, D2.1 (K), D3.1 (A1), D4.1 (A1), D5.1 (A1), H1.1 (1_1), H2.1 (1_1), H3.1 (1_1), H4.1 (1_1), J1.A1 (GND_A), J1.B1 (GND_B), J2.2, J2.8, J3.12, J4.2 (Ext), J5.2 (Ext), J6.2 (Ext), J7.2, J7.3, R4.2, R7.1, R9.2, R10.2, R14.2, R15.2, R24.2, U1.4 (GND), U2.2 (GND), U3.47 (VREG_PGND), U3.61 (GND), U4.6 (DGND), U4.15 (PGND), U4.18 (AGND), U4.29 (DGND), U4.32 (GND_IO), U4.33 (AGND), U5.5 (VSS), U6.5 (GND), U7.1 (PGND), U7.4 (AGND), U7.8 (PG), U7.9 (PAD), U8.2 (GND), U9.2 (GND), Y1.2 (G), Y1.4 (G)
unnamed: BT1.1 (+), C21.1, U5.6 (VBACKUP)
unnamed: C4.1, R3.1, Y1.1
unnamed: C11.2, J1.S1 (SHIELD), J1.S2 (SHIELD), J1.S3 (SHIELD), J1.S4 (SHIELD), R7.2
unnamed: C29.2, R17.1
unnamed: C31.1, C32.1, R20.1
unnamed: C31.2, C32.2, FB2.1
unnamed: C33.1, C34.1, R22.1
unnamed: C33.2, C34.2, FB3.1
unnamed: C36.1, C37.1, R21.2
unnamed: C36.2, C37.2, FB4.1
unnamed: D1.2 (A), J1.A4 (VBUS_A), J1.B4 (VBUS_B), U2.5 (VBUS)
unnamed: D2.2 (A), R8.2
unnamed: D3.2 (A2), FB2.2, J4.1 (In)
unnamed: D4.2 (A2), FB3.2, J5.1 (In)
unnamed: D5.2 (A2), FB4.2, J6.1 (In)
unnamed: D6.2 (A), J7.1
unnamed: C38.1, C39.1, D6.1 (K), U7.2 (VIN), U7.3 (EN)
unnamed: J1.A5 (CC1), R10.1
unnamed: J1.B5 (CC2), R9.1
unnamed: J1.A6 (D1+), J1.B6 (D2+), U2.3 (I/O2)
unnamed: J1.A7 (D1-), J1.B7 (D2-), U2.1 (I/O1)
unnamed: J2.1, U3.12 (GPIO8)
unnamed: J2.3, U3.13 (GPIO9)
unnamed: J2.5, U3.14 (GPIO10)
unnamed: J2.7, U3.15 (GPIO11)
unnamed: J3.1, U3.35 (GPIO23)
unnamed: J3.2, U3.36 (GPIO24)
unnamed: J3.3, U3.40 (GPIO26/ADC0)
unnamed: J3.4, U3.41 (GPIO27/ADC1)
unnamed: J3.5, U3.42 (GPIO28/ADC2)
unnamed: J3.6, U3.43 (GPIO29/ADC3)
unnamed: J3.7, U3.34 (GPIO22)
unnamed: J3.8, U3.33 (GPIO21)
unnamed: J3.9, U3.32 (GPIO20)
unnamed: J3.10, U3.31 (GPIO19)
unnamed: L2.1, U2.6 (I/O1)
unnamed: L2.2, R5.1
unnamed: L2.3, U2.4 (I/O2)
unnamed: L2.4, R6.1
unnamed: R4.1, SW1.1
unnamed: R17.2, R19.2
unnamed: U1.6 (CLK), U3.56 (QSPI_SCLK)
unnamed: U1.5 (DI/IO_{0}), U3.57 (QSPI_SD0)
unnamed: U1.2 (DO/IO_{1}), U3.59 (QSPI_SD1)
unnamed: R1.2, SW1.2, U1.1 (~CS), U3.60 (~QSPI_SS)
unnamed: U1.7 (~HOLD/~RESET/IO_{3}), U3.55 (QSPI_SD3)
unnamed: U1.3 (~WP/IO_{2}), U3.58 (QSPI_SD2)
unnamed: U3.2 (GPIO0), U4.9 (P7)
unnamed: U3.3 (GPIO1), U4.8 (P6)
unnamed: U3.4 (GPIO2), U4.7 (P5)
unnamed: U3.5 (GPIO3), U4.4
unnamed: U3.7 (GPIO4), U4.3
unnamed: U3.8 (GPIO5), U4.2
unnamed: U3.9 (GPIO6), U4.31 (P1)
unnamed: U3.10 (GPIO7), U4.30 (P0)
unnamed: U3.16 (GPIO12), U4.13 (CLKIN)
unnamed: U3.17 (GPIO13), U4.27 (~HSYNC)
unnamed: U3.18 (GPIO14), U4.26 (~VSYNC)
unnamed: C17.1, R11.1, U3.19 (GPIO15), U4.14 (~RESET)
unnamed: R13.1, U3.27 (GPIO16), U4.11 (SDA), U5.4 (SDA)
unnamed: R12.1, U3.28 (GPIO17), U4.12 (SCL), U5.3 (SCL)
unnamed: U3.29 (GPIO18), U4.25 (SFL)
unnamed: R8.1, U3.37 (GPIO25)
unnamed: R5.2, U3.51 (USB_DM)
unnamed: R6.2, U3.52 (USB_DP)
unnamed: C6.1, R2.2, U3.46 (VREG_AVDD)
unnamed: C1.1, C7.1, C8.1, C9.1, L1.1, U3.6 (DVDD), U3.23 (DVDD), U3.39 (DVDD), U3.50 (VREG_FB)
unnamed: L1.2, U3.48 (VREG_LX)
unnamed: C3.1, U3.21 (XIN), Y1.3
unnamed: R3.2, U3.22 (XOUT)
unnamed: C26.2, U4.23 (COMP)
unnamed: R15.1, U4.22 (DAC1), U6.1 (CH1IN), U6.2 (CH2IN), U6.3 (CH3IN)
unnamed: C29.1, C30.1, U4.16 (EXT_LF)
unnamed: C22.1, C24.1, C30.2, FB1.2, R19.1, U4.17 (P_{VDD})
unnamed: R14.1, U4.24 (R_{SET})
unnamed: R18.2, U5.8 (EVI)
unnamed: R16.2, U5.2 (~INT)
unnamed: R20.2, U6.8 (CH1OUT)
unnamed: R22.2, U6.7 (CH2OUT)
unnamed: R21.1, U6.6 (CH3OUT)
unnamed: R23.2, R24.1, U7.5 (FB)
unnamed: L3.1, U7.7 (SW)
unnamed: C40.1, L3.2, L4.1, R23.1, U7.6 (VOS)

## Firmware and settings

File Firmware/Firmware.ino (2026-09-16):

// PAL-sign, the main tab: setup(), loop(), setup1(), loop1(), serial
// commands, the card list. Rest of the firmware is under src/.
// sketch.yaml sets the board profile ("palsign"): Olimex Pico2XXL,
// 16MB flash (3MB sketch / 13MB FS, fixed -- photos and settings live
// in the FS part via _FS_start/_FS_end). CPU speed: setup() sets its
// own clock, must be a multiple of 54 MHz; see CFG_SYSCLK_HZ in
// src/config.h.

// Philips test card generator for the RP2350 and an ADV7391, on an
// Olimex RP2350-PICO2-XXL. PAL B/G composite (CVBS) over BT.656 with
// embedded sync, from the original EPROM dumps of a Philips PM5644.
//
// Wiring (connector J1, "DATA"); board.h has the pin map.
//
//   J1     ADV7391      Olimex XXL
//   1..8   P0..P7       GP0..GP7    pixel bus
//   9      CLKIN        GP12        through JP1, DATA side (pins 2-3)
//   10     ~HSYNC       GP13        also PCM1808 SCKI, see below
//   11     ~VSYNC       GP14        held high, see below
//   12     SFL          GP18        held low, see below
//   13     ~RESET       GP15
//   14     SCL          GP17        I2C0
//   15     SDA          GP16        I2C0
//   16     GND          GND
//
// GP8 is off limits (PSRAM chip select); GP9-11 carry the PCM1808
// experiment now (BCK/LRCK/DOUT, see board.h and src/pcm1808.h), so
// there is no free pin left for the microSD that was never built.
//
// HSYNC/VSYNC held high: unused in slave Timing Mode 0 (datasheet
// p.72 requires unused VSYNC/HSYNC HIGH; safe to drive hard only
// because they stay inputs in this mode, p.16). GP13/~HSYNC has been
// handed to pio1 instead, as the PCM1808's system clock: still safe
// for the same reason, and confirmed further by applyOperatingConfig()
// in adv7391.cpp never touching register 0x02 (SD sync output stays at
// its reset default, off), so the encoder never drives this pin either.
//
// SFL held low (timing reset mode, register 0x84 bits[2:1] = 10): a
// pulse resets the encoder's field counter to Field 1, subcarrier
// phase zero (p.46); see videoRequestSflPulse().
#include <Arduino.h>
#include <hardware/watchdog.h>   // watchdog_caused_reboot(), the factory-reset gate
#include <stdarg.h>

#include <hardware/clocks.h>
#include <hardware/regs/addressmap.h>

#include "src/adv7391.h"
#include "src/aspect.h"
#include "src/board.h"
#include "src/clock.h"
#include "src/config.h"
#include "src/display.h"
#include "src/encoder.h"
#include "src/flashspeed.h"
#include "src/gfx.h"
#include "src/photoflash.h"
#include "src/portrait.h"
#include "src/inserts.h"
#include "src/its.h"
#include "src/language.h"
#include "src/movingline.h"
#include "src/pattern.h"
#include "src/pcm1808.h"
#include "src/asrc.h"
#include "src/rompattern.h"
#include "src/rv3028.h"
#include "src/settings.h"
#include "src/teletext.h"
#include "src/textoverlay.h"
#include "src/ticker.h"
#include "src/video.h"
#include "src/videoloop.h"

// Order is stored by position: per-card settings, start card and
// sequence steps all reference a card by its index here. Reordering
// or inserting needs a new CARD_VERSION and a migration in
// settings.cpp (CARD_ORDER_V2, cardShiftV4, CARD_ORDER_V5, cardShiftV7).
static const Pattern *const PATTERNS[] = {
    &PATTERN_PM5644G00,  &PATTERN_FUBKNOCIRCLE, &PATTERN_FUBK4X3,   &PATTERN_BARSRED,
    &PATTERN_TESTCARDF,  &PATTERN_TESTCARDG,    &PATTERN_TVE,
    &PATTERN_MIXEDBAR,   &PATTERN_PICDREAM,
    &PATTERN_PM5644G924, &PATTERN_FUBK16X9,     &PATTERN_TESTCARDW, &PATTERN_INTERNBAR,
    &PATTERN_PM5644G913, &PATTERN_EBUBW,        &PATTERN_PULSEBAR,  &PATTERN_SINXX,
    &PATTERN_MULTIBURST, &PATTERN_CROSSHATCH,   &PATTERN_CONTEST,
    &PATTERN_CUSTOM1,      &PATTERN_CUSTOM2,   &PATTERN_CUSTOM3,
    &PATTERN_CUSTOM4,      &PATTERN_CUSTOM5,    &PATTERN_CUSTOM6,    &PATTERN_CUSTOM7,
    &PATTERN_CUSTOM8,      &PATTERN_CUSTOM9,    &PATTERN_CUSTOM10,   &PATTERN_CUSTOM11,
    &PATTERN_CUSTOM12,     &PATTERN_CUSTOM13,   &PATTERN_CUSTOM14,
    &PATTERN_PCMAUDIO, &PATTERN_SONYPCM};
static const int PATTERN_COUNT = (int)(sizeof(PATTERNS) / sizeof(PATTERNS[0]));

// The worst row build time since the last timing report; see the
// report for why the lifetime figures are not enough.
static volatile uint32_t timingWindowWorstUs = 0;
static_assert(CFG_PATTERN >= 0 && CFG_PATTERN < PATTERN_COUNT, "CFG_PATTERN out of range");

const Pattern *activePattern = PATTERNS[CFG_PATTERN];
static int patternIndex = CFG_PATTERN;
static bool timingOn = CFG_TIMING_REPORT;

// True while the card dump job is streaming a picture to the PC.
static bool dumpActive = false;

// Only writes when the USB buffer can take it without blocking (a
// blocking write here drops the picture), and never during a dump, or
// the report would land inside the picture bytes.
static void report(const char *fmt, ...) {
  if (dumpActive) return;
  char msg[200];
  va_list ap;
  va_start(ap, fmt);
  int n = vsnprintf(msg, sizeof(msg), fmt, ap);
  va_end(ap);
  if (Serial && n > 0 && n < (int)sizeof(msg) && Serial.availableForWrite() >= n) {
    Serial.write(msg, n);
  }
}

// A card change costs nearly 10 ms with no rows built, against a ~4 ms
// ring buffer, so a key press is only noted and carried out in the
// frame loop, at most once per SWITCH_MIN_MS; extra presses are dropped.
static int requestedPattern = -1;

// What the encoder is pointing at, or -1 for the card already showing.
// The picture changes on press, not on turn.
static int encoderCandidate = -1;

// millis() of the last turn; a candidate untouched for
// CANDIDATE_TIMEOUT_MS is cancelled. Meaningful only while
// encoderCandidate >= 0.
static uint32_t encoderCandidateLastMs = 0;
static const uint32_t CANDIDATE_TIMEOUT_MS = 3000;

// How long a card change may wait for the ring buffer to refill after a
// write (zero: not waiting).
static const uint32_t SWITCH_WAIT_MAX_MS = 500;
static uint32_t switchWaitMs = 0;
static uint32_t lastSwitchMs = 0;
static const uint32_t SWITCH_MIN_MS = 400;

// Whether a card's ROM tables copy in one go or need pieces, once known;
// found out the first time each card is switched to, kept for the rest
// of the run. See romLoad().
static bool cardCopyInOneGo[PATTERN_COUNT];

// State of a switch still running, so the report waits until the copy
// has actually finished.
static VideoStats switchBefore;
static uint32_t switchStartUs = 0;
static bool switchRunning = false;
static uint32_t switchLastStarves = 0;

// Prints how the last switch went.
static void reportSwitch() {
  VideoStats now;
  videoGetStats(&now);
  switchRunning = false;
  // A switch a flash write ran into empties the ring regardless of the
  // card, so that must not count against it.
  if (romCopyPanicked() && now.flashLines == switchBefore.flashLines) {
    cardCopyInOneGo[patternIndex] = true;
  }
  report(LANG_CARD_D_D_S_LU,
         patternIndex + 1, PATTERN_COUNT, activePattern->name,
         (unsigned long)(micros() - switchStartUs),
         (unsigned long)(now.starves - switchBefore.starves),
         (unsigned long)(now.txStalls - switchBefore.txStalls),
         romCopyForced() ? LANG_COPIED_IN_ONE_GO : LANG_COPIED_IN_PIECES);
}

// Enabled, and, for a photograph slot, actually holding a picture: an
// empty slot always reads as off regardless of the stored flag. Shared
// by nextPattern(), the "[card]" dump's enabled= field, and the panel's
// card count.
// The two PCM sound cards carry the PCM1808's audio and are silence
// without it; when the boot probe found no ADC (pcm1808Present()) they
// disappear completely: not selectable, not listed to the PC tool, not
// in the panel menu, not counted. Everything else is always available.
static bool cardIsAvailable(int i) {
  if (PATTERNS[i] != &PATTERN_PCMAUDIO && PATTERNS[i] != &PATTERN_SONYPCM) return true;
  return pcm1808Present();
}

static bool cardIsEnabled(int i) {
  const int slot = customSlotOf(PATTERNS[i]);
  return cardIsAvailable(i) && cfgCardEnabled(i) && (slot < 0 || photoValid(slot));
}

// How many cards cardIsEnabled() counts, and index's rank among them,
// board order, 1 based: the panel's "N/M".
static int enabledPatternCount() {
  int n = 0;
  for (int i = 0; i < PATTERN_COUNT; i++) {
    if (cardIsEnabled(i)) n++;
  }
  return n;
}

static int enabledPatternRank(int index) {
  int n = 0;
  for (int i = 0; i <= index; i++) {
    if (cardIsEnabled(i)) n++;
  }
  return n;
}

// The next card in that direction, skipping empty photograph slots and
// disabled cards; typing the number still reaches either.
static int nextPattern(int from, int step) {
  int i = from;
  for (int n = 0; n < PATTERN_COUNT; n++) {
    i = (i + step + PATTERN_COUNT) % PATTERN_COUNT;
    if (cardIsEnabled(i)) return i;
  }
  return from;
}

// THIS DOES NOT WRITE ANYTHING; remembering the choice is the caller's
// business, a picture earlier (see the card change in videoFrameHook()).
static void selectPattern(int i) {
  if (i < 0 || i >= PATTERN_COUNT) return;

  encoderCandidate = -1;

  // A switch whose copy has not finished yet is overtaken by this one;
  // report it first so its figures are not lost or mixed with the next.
  if (switchRunning) reportSwitch();
  switchLastStarves = 0;

  videoGetStats(&switchBefore);
  switchStartUs = micros();
  switchRunning = true;

  // Let go of the miniature before init(), so a card that draws its own
  // only has to say so, never to undo it; see displayThumbHold().
  displayThumbHold(false);

  // Applied before init(): a card lays its text out around these, and
  // insertClearInUse() below reads what the card being left just drew.
  cfgSetActiveCard(i);

  insertClearInUse();
  movingLineClearInUse();
  aspectSet(cfgCardAspect(-1));
  insertSetMode(cfgCardInsert(-1));
  // An uploaded photograph reads its rows out of flash; a transparent
  // band on top does not fit the row budget.
  tickerAllowTransparent(customSlotOf(PATTERNS[i]) < 0);
  textInkRefresh();
  textSetFont(cfgCardTextFont(-1));
  tickerBegin();

  PATTERNS[i]->init();
  // A reload asked for on the way here is already answered by the
  // init() just done; without this the frame hook would run it again.
  cfgReloadDone();
  activePattern = PATTERNS[i];
  patternIndex = i;
  advSetMonochrome(PATTERNS[i]->mono);
  advSetColourBars(PATTERNS[i]->encoderMakesIt);

  // Known already unable to keep up, so skip spending rows to find out
  // again.
  if (cardCopyInOneGo[i]) romCopyFinish();

  // A card that cost nothing is done here; everything else waits for
  // videoFrameHook(), which reports as soon as rows stop coming late.
  VideoStats now;
  videoGetStats(&now);
  if (!romCopyPending() && now.starves == switchBefore.starves) {
    reportSwitch();
  } else {
    switchLastStarves = now.starves;
  }
}

// --- the slideshow ---------------------------------------------------
//
// Steps through the filled photograph slots, with a short fade to black
// between them. The fade is done by the encoder (advSetFade(), three
// registers in the Y/Cb/Cr scaling after sync), not in the rows, which
// have no time to spare for it. The card is switched at full black, so
// a heavy card's late rows while it copies fall inside the fade.
static const uint32_t SLIDE_HOLD_MS = 2000;

// One step a picture, 25/s: 240 ms down, 400 ms up. Fade in is longer,
// since that is the one you watch.
static const int SLIDE_FADE_OUT_STEPS = 6;
static const int SLIDE_FADE_IN_STEPS = 10;

// Caps the wait at black so a card that never settles cannot leave the
// slideshow stuck in the dark. 25 pictures is a second.
static const int SLIDE_WAIT_MAX = 25;

enum SlidePhase { SLIDE_SHOWING, SLIDE_OUT, SLIDE_BLACK, SLIDE_IN };

static bool slideshowOn = false;
static SlidePhase slidePhase = SLIDE_SHOWING;
static uint32_t slideHoldUntil = 0;
static int slideStep = 0;
static int slideWaited = 0;
static bool slideSwitched = false;
static int slideSeqIndex = -1;     // where in the sequence, -1 = not started
static uint32_t slideCurrentMs = SLIDE_HOLD_MS;

// The next filled, enabled photograph slot after `from`, or -1: the
// fallback when no sequence is given.
static int nextFilledCustom(int from) {
  for (int n = 0; n < PATTERN_COUNT; n++) {
    const int i = (from + 1 + n) % PATTERN_COUNT;
    if (!cfgCardEnabled(i)) continue;
    const int slot = customSlotOf(PATTERNS[i]);
    if (slot >= 0 && photoValid(slot)) return i;
  }
  return -1;
}

// Which card comes next and how long it stands. A sequence decides both;
// without one it is the next filled slot for SLIDE_HOLD_MS.
static bool slideNext(int *card, uint32_t *ms) {
  const int n = cfgSeqCount();
  if (n > 0) {
    // Steps over entries whose card is not available (a PCM card with
    // no ADC attached): the show goes on with the rest, and gives up
    // only when nothing in the sequence is available.
    for (int tries = 0; tries < n; tries++) {
      if (slideSeqIndex < 0 || slideSeqIndex >= n - 1) {
        slideSeqIndex = 0;
      } else {
        slideSeqIndex++;
      }
      const int c = cfgSeqCard(slideSeqIndex);
      if (c < 0 || c >= PATTERN_COUNT || !cardIsAvailable(c)) continue;
      *card = c;
      *ms = cfgSeqMs(slideSeqIndex);
      return true;
    }
    return false;
  }
  const int next = nextFilledCustom(patternIndex);
  if (next < 0) return false;
  *card = next;
  *ms = SLIDE_HOLD_MS;
  return true;
}
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
void loop() {
  static uint32_t line = 1;
  // Hooks back onto the streamer after a videoSuspend()/videoResume():
  // it carried on with blank rows, so its line counter sits somewhere
  // mid-picture, given by "ring slot k belongs to line (k % 625) + 1".
  // Not line 1: the line and field structure was never interrupted, so
  // jumping back to line 1 would give a picture that is too short.
  if (videoRestartRequest) {
    videoRestartRequest = false;
    line = (videoProducedCount % VIDEO_LINES_PER_FRAME) + 1;
  }
  // VIDEO_RING_SIZE - 3: the chained DMA always has two rows under way
  // (being sent, and already loaded into the other channel), which the
  // producer must keep away from.
  //
  // Waits for core1, but not forever: if the streamer never comes back
  // core0 would stand here for good and the whole board would be dead,
  // which is exactly what happened after a failed upload once. After
  // half a second it carries on anyway, disturbing the picture but
  // keeping the board usable; the counter below makes it visible.
  {
    uint32_t t0 = time_us_32();
    // Signed compare: just after videoResume() the producer can be
    // briefly behind the streamer, which would flip the unsigned
    // difference to nearly 2^32 and trigger an unneeded half-second wait.
    while ((int32_t)(videoProducedCount - videoConsumedCount) >= (int32_t)(VIDEO_RING_SIZE - 3)) {
      if (time_us_32() - t0 > 500000) {
        videoStallCount++;
        break;
      }
      tight_loop_contents();
    }
  }

  // Two answers, since the display's two halves are not equally
  // expensive: sampling the miniature (26 us) fits outside a card
  // change with room to spare, but the 152 us transfer pulls the stock
  // down and waits for room. Gating both on the stock was too strict:
  // a single unlucky missed band could leave a card like TVE black for
  // good, since the miniature only sends once all 76 bands are in.
  //
  // The encoder is read here, once per row (every 64 us): a hand
  // turning twenty detents a second is eighty edges against 15625
  // samples, three orders of margin, and the 25 Hz frame hook would
  // drop steps.
  encoderPoll();

  const bool noCardChange = !romCopyPending();
  // The ticker gets the same treatment as the display, and for the same
  // reason: the copy only runs while the ring buffer is above its
  // threshold, and the band is what pulls it down.
  tickerPause(!noCardChange);
  videoDisplaySample = noCardChange;
  videoDisplayMayWork = noCardChange &&
                   (int32_t)(videoProducedCount - videoConsumedCount) > VIDEO_DISPLAY_KEEP_ROWS;
  uint32_t t0 = time_us_32();
  videoBuildLine(videoRing[videoProducedCount % VIDEO_RING_SIZE], line);
  uint32_t dt = time_us_32() - t0;
  if (dt > videoWorstBuildUs) videoWorstBuildUs = dt;
  if (dt < videoMinBuildUs) videoMinBuildUs = dt;
  if (dt > timingWindowWorstUs) timingWindowWorstUs = dt;
  videoSumBuildUs += dt;
  videoSampleCount++;
  if (dt > VIDEO_LINE_BUDGET_US) videoOverBudgetCount++;

  // Pushes a card change along: romLoad() hands its table copy in as a
  // job rather than all at once, only while the ring buffer holds more
  // than VIDEO_ROM_COPY_KEEP_ROWS rows, which is what makes it safe: it
  // only uses time the producer would otherwise wait on core1, and
  // gives that time back the moment the stock runs down.
  videoProducedCount++;
  if (romCopyPending()) {
    int32_t stock = (int32_t)(videoProducedCount - videoConsumedCount);
    if (stock < VIDEO_ROM_COPY_PANIC_ROWS) {
      // Decoding from flash costs more per row than from RAM; on the
      // heaviest card, more than a row's 64 us (measured 64.4 us for a
      // PM5644 16:9 row's decode), so that card never catches up and
      // the copy never gets its turn.
      //
      // So when the stock really runs down, finish the copy in one go:
      // a card that fits gets a clean switch, one that does not falls
      // back here and pays the KEEP-to-PANIC stock, about 1 ms.
      romCopyPanic();
    } else {
      while ((int32_t)(videoProducedCount - videoConsumedCount) > VIDEO_ROM_COPY_KEEP_ROWS) {
        if (!romCopyStep(VIDEO_ROM_COPY_CHUNK)) break;
      }
    }
  }

  // The transfer, under the same rule as the sampling. See
  // videoDisplayMayWork above. While a card dump runs, the display
  // only takes a slot with four rows more in stock: it comes first in
  // this loop and a 152 us chunk costs 2.4 rows of stock, so on a card
  // whose rows take 55 us (Ham PCM LQ) it pulled the stock back to the
  // threshold every time and the dump below never got a turn (the PC
  // tool sat on "fetching" with not one row received). The band from
  // KEEP to KEEP + 4 is the dump's.
  const bool displayMay = videoDisplayMayWork &&
      (!dumpActive || (int32_t)(videoProducedCount - videoConsumedCount) > VIDEO_DISPLAY_KEEP_ROWS + 4);
  if (displayMay && displayBusy()) displayStep(VIDEO_DISPLAY_CHUNK);

  // The card dump, under the same rule again: one bounded piece per
  // spare slot, and only while the stock can carry it. See
  // cardDumpStep().
  if (dumpActive && noCardChange &&
      (int32_t)(videoProducedCount - videoConsumedCount) > VIDEO_DISPLAY_KEEP_ROWS)
    cardDumpStep();

  line++;
  if (line > VIDEO_LINES_PER_FRAME) {
    line = 1;
    videoFrameHook();
  }
}

// --- Core1 -----------------------------------------------------------
void setup1() {
  flashSpeedWaitReady();
  videoStartPio();
  videoStreamBegin();
}

// Core1: the streamer. One row per turn, never waits.
//
// __not_in_flash_func is not a luxury here: while core0 writes to
// flash, core1 may not touch the XIP space, and this way it carries on.
//
// Between two turns core1 is in flash, in main1()'s while loop, which
// is allowed: core0 does not start erasing until videoParked is true,
// set only at the bottom of this function from inside the wait that
// follows it, so core1 is always inside this function, in RAM, for the
// whole of a write.
//
// Check after every change with arm-none-eabi-objdump -d on the elf:
// loop1, videoLoadLine, lineKind, videoKickChain, videoSflStep and
// videoCountTxStall must all sit at an address in 0x2000_0000.., and no
// bl out of them may go to 0x1000_0000..
void __not_in_flash_func(loop1)() {
  static int arm = 0;      // 0 = reload channel A, 1 = channel B
  int ch = arm ? videoDmaChanB : videoDmaChanA;
  videoLoadLine(ch, false);
  arm ^= 1;
  videoKickChain(ch);
  videoSflStep();
  videoCountTxStall();

  // Core0 wants to write to flash: from here to the end of this loop no
  // instruction runs out of XIP space and interrupts are off; the chain
  // carries on with blank rows.
  if (videoParkRequest) {
    // save_and_disable_interrupts() from the pico-sdk, not
    // noInterrupts() from the Arduino layer: that one lives in flash
    // (arm-none-eabi-nm: 1000ce10 T interrupts, 1000ce44 T
    // noInterrupts), called through a veneer, and would give exactly
    // the bus fault this is avoiding. The sdk variant produces bare
    // instructions; the disassembly shows mrs/cpsid/msr and no bl.
    uint32_t st = save_and_disable_interrupts();
    videoParked = true;
    while (videoParkRequest) {
      int c = arm ? videoDmaChanB : videoDmaChanA;
      videoLoadLine(c, true);
      arm ^= 1;
      videoKickChain(c);
      videoSflStep();
      videoCountTxStall();
    }
    videoParked = false;
    restore_interrupts(st);
  }
}

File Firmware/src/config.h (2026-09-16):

// The settings you are most likely to want to change.
//
// The other knobs sit with the code they belong to:
//   pm5644g00.cpp  the positions of the text boxes
//   adv7391.cpp    the luma filter (also live with 1/2/3 over serial)
//   platformio.ini the clock speed
#ifndef CONFIG_H
#define CONFIG_H

#include <stdint.h>

// The version on the splash of the little panel.
#define CFG_VERSION "v1.00"

// Station identification. Allowed: A-Z, 0-9, space, the slashed O and
// : ! ? / @ # * _ + < > - . , = ( )   Lower case becomes upper case.
static const char CFG_TEXT_ID[] = "MYCALL";
static const char CFG_TEXT_SUB[] = "MYQTH";

// --- Ticker ----------------------------------------------------------
//
// One line of text scrolling right to left across the picture. Off by
// default. CFG_TICKER_Y is the top row, clamped on screen and rounded
// to an even row (an odd edge flickers between fields). CFG_TICKER_FONT
// indexes FONTS[] in font_data.h. Whether the ticker shows is kept per
// card, see cfgCardTicker() in settings.h.
static const int CFG_TICKER_Y = 530;
static const int CFG_TICKER_FONT = 0;
static const char CFG_TICKER_TEXT[] = "TEST CARD PAL-SIGN";

// Which of the five fixed sizes the big faces (Inter, Doto) draw at;
// see settings.h's TICKER_SIZE_MIN/MAX and ticker.cpp's
// TICKER_SIZE_COUNT. 2 is medium, the one size both faces had before
// this feature existed.
static const int CFG_TICKER_SIZE = 2;

// --- Insert boxes (the ROM test card only) ---------------------------
//
// Middle left and middle right. Part of the EPROM data itself, so
// switching mode switches the picture data too, not just the text.
//
//   0 = no boxes, the grid carries on   (pat2)
//   1 = the time only                   (pat1)
//   2 = date and time                   (pat0)
//   3 = the fixed texts below           (pat0)
//
// Key i walks 0, 1 and 2. Mode 3 is chosen over the port. Each box is
// 148 x 40 px, about 8 characters.
static const int CFG_INSERT_MODE = 2;

// The starting point for mode 3, kept in flash from then on.
#define CFG_ENCODER_ON 1

// Whether the firmware build counts in the card checksum: on, every
// reflash costs the PC all pictures. Off while the firmware is under
// active work.
static const bool CFG_CARD_CRC_BUILD_ID = false;

// How bright the little panel is, 0 to 100.
static const int CFG_DISPLAY_BRIGHTNESS = 100;

static const char CFG_TEXT_INSERT_LEFT[] = "FIXED";
static const char CFG_TEXT_INSERT_RIGHT[] = "TEXT";

// --- The G924 test card only ----------------------------------------
//
// The two narrow chroma test bars left/right, the PAL switch test.
static const bool CFG_G924_CHROMA_BARS = true;

// --- Test Card G only -------------------------------------------------
//
// The two variants differ only in the block at the top left.
// false = AP1, true = AP2.
static const bool CFG_TESTCARDG_AP2 = false;

// --- The slideshow's fade ----------------------------------------------
//
// Off cuts straight to black and back instead of a gradual dip.
static const bool CFG_SLIDE_FADE_ON = true;

// --- The clock's EU summer time ----------------------------------------
static const bool CFG_DST_AUTO_ON = false;

// --- Flash speed ------------------------------------------------------
//
// clk_sys divided by this number. 0 leaves the QMI as the bootrom set
// it up. The W25Q128JV is rated for 133 MHz; flashSpeedApply() carries
// a static_assert on sysclk/divisor so a wrong combination fails the
// build.
static const int CFG_FLASH_CLKDIV = 1;

// THE SYSTEM CLOCK, set by the firmware itself. The PIO program needs
// sysclk / divisor / 2 = 27 MHz exactly, so sysclk must be a multiple
// of 54 MHz; 108 is the highest such multiple within the RP2350's
// 150 MHz rating. See the workbook before raising this.
static const uint32_t CFG_SYSCLK_HZ = 108000000;

// Pixel bus wired mirrored: P7 on the lowest data GPIO through P0 on
// the highest, which lets the PCB route the bus without crossing eight
// tracks. 0 for a straight bus, 1 for a mirrored one; the reversal
// costs no CPU, see bt656_out_rev in bt656.pio. With 1 the sysclk must
// be a multiple of 108 MHz (four state-machine cycles per CLKIN period
// instead of two).
#define CFG_PIXEL_BUS_REVERSED 1

// --- Clock ------------------------------------------------------------
//
// No battery backed RTC: after a power cut the clock starts again here.
// Settable live over serial: T2026-08-09 14:30:00 or T14:30:00.
static const int CFG_CLOCK_START_YEAR = 2026;
static const int CFG_CLOCK_START_MONTH = 1;
static const int CFG_CLOCK_START_DAY = 1;
static const int CFG_CLOCK_START_HOUR = 0;
static const int CFG_CLOCK_START_MIN = 0;
static const int CFG_CLOCK_START_SEC = 0;

// Date format in the left insert box:
//   0 = DD-MM-YY    (09-08-26)
//   1 = DD-MM-YYYY  (09-08-2026)
//   2 = YYYY-MM-DD  (2026-08-09)
static const int CFG_DATE_FORMAT = 0;
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

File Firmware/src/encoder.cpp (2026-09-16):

#include "encoder.h"

#include <Arduino.h>
#include <pico.h>   // __not_in_flash_func

#include "board.h"
#include "config.h"

#if CFG_ENCODER_ON

// Quadrature transition table, indexed by (old code << 2 | new code):
// +1/-1 for a real Gray code step, 0 for no movement or an impossible
// two-step jump (contact bounce).
static const int8_t STEP[16] = {
    0, +1, -1, 0,
    -1, 0, 0, +1,
    +1, 0, 0, -1,
    0, -1, +1, 0,
};

static volatile int16_t steps = 0;

// No time debounce; the discipline is the Gray code itself, a full
// four-quarter commit with a reset at rest.
static uint8_t oldAB = 3;   // rest: both phases pulled up
static int8_t encval = 0;

// Nothing commits until BOOT_GUARD_US after encoderBegin(), so a
// spurious edge while the pull-ups settle at power-on cannot register.
// One-shot on purpose: (int32_t)(now - deadline) >= 0 is a 2^31 us
// window, not a threshold. Left armed, it went false again 35.8
// minutes after boot and the knob fell silent for the next 35.8,
// alternating forever: the ISR kept running and encval kept completing
// clicks while steps stayed 0 (measured with key M, 30 August 2026).
static const uint32_t BOOT_GUARD_US = 300000;
static uint32_t encoderReadyUs = 0;
static bool bootGuardPassed = false;

static inline bool __not_in_flash_func(bootGuardOver)() {
  if (!bootGuardPassed && (int32_t)(time_us_32() - encoderReadyUs) >= 0) bootGuardPassed = true;
  return bootGuardPassed;
}

static void __not_in_flash_func(encoderIsr)() {
  const uint8_t code = (uint8_t)((gpio_get(PIN_ENC_A) << 1) | gpio_get(PIN_ENC_B));
  oldAB = (uint8_t)((oldAB << 2) | code);
  encval = (int8_t)(encval + STEP[oldAB & 0x0f]);

  // Unstick: four straight impossible jumps would otherwise oscillate
  // forever without reaching rest.
  if (!(uint8_t)(255 - oldAB)) encval = 0;

  if (encval > 3) {
    if (bootGuardOver()) steps++;
    encval = 0;
  } else if (encval < -3) {
    if (bootGuardOver()) steps--;
    encval = 0;
  }

  // A partial count that never reached a full click drops once the
  // pins return to rest (code 3, both phases high).
  if ((oldAB & 0x03) == 0x03) encval = 0;
}

// 20 ms of agreement at 64 us a sample, kept in samples so no millis()
// call is needed on the row path.
static const uint16_t PUSH_STABLE = 313;
static uint16_t pushSame = 0;
static bool pushState = true;   // pulled up, so true is not pressed
static volatile bool pushed = false;

// Same debounce as the press: letting go can nudge the shaft too. See
// MENU_TURN_GUARD_MS in Firmware.ino, which arms on this as well.
static volatile bool released = false;

// Fires while still held, not on release, so the menu opens under your
// thumb.
static const uint32_t LONG_PRESS_US = 2000000;
static uint32_t pushDownUs = 0;
static bool longFired = false;
static volatile bool longPress = false;

// Set once encoderBegin() has actually run, so encoderPresent() answers
// "did this board get one" rather than just "was the feature compiled
// in" -- the front panel carrying the knob can be unplugged at runtime
// (see PIN_FRONT_PRESENT in board.h), which CFG_ENCODER_ON cannot see.
static bool began = false;

void encoderBegin() {
  pinMode(PIN_ENC_A, INPUT_PULLUP);
  pinMode(PIN_ENC_B, INPUT_PULLUP);
  pinMode(PIN_ENC_PUSH, INPUT_PULLUP);
  oldAB = (uint8_t)((digitalRead(PIN_ENC_A) << 1) | digitalRead(PIN_ENC_B));
  encval = 0;
  steps = 0;
  encoderReadyUs = time_us_32() + BOOT_GUARD_US;
  bootGuardPassed = false;
  pushState = true;
  pushSame = 0;
  attachInterrupt(digitalPinToInterrupt(PIN_ENC_A), encoderIsr, CHANGE);
  attachInterrupt(digitalPinToInterrupt(PIN_ENC_B), encoderIsr, CHANGE);
  began = true;
}

// Rotation commits in encoderIsr(); this only polls the push switch,
// which needs repeated sampling to debounce a level. A no-op before
// encoderBegin() has run: PIN_ENC_PUSH is not yet a configured input,
// so reading it here would be a floating pin, not a real switch.
void __not_in_flash_func(encoderPoll)() {
  if (!began) return;
  // Closes the boot-guard latch on time alone, every 64 us row. Left
  // to the ISR the latch only closed when a click happened to land in
  // the positive half of the 2^31 us window; a first touch of the
  // knob 40+ minutes after boot found it still open with the window
  // negative, and rotation stayed dead again (found in review,
  // 31 August 2026). From here the first row 300 ms after boot
  // closes it for good.
  bootGuardOver();
  const bool now = gpio_get(PIN_ENC_PUSH) != 0;
  if (now == pushState) {
    pushSame = 0;
  } else if (++pushSame >= PUSH_STABLE) {
    pushSame = 0;
    pushState = now;
    if (!now) {   // the press, not the release, so the change is under your thumb
      pushed = true;
      pushDownUs = time_us_32();
      longFired = false;
    } else {
      released = true;
    }
  }
  if (!pushState && !longFired && time_us_32() - pushDownUs >= LONG_PRESS_US) {
    longFired = true;
    longPress = true;
  }
}

int encoderTakeSteps() {
  noInterrupts();   // steps is written from encoderIsr()
  const int16_t n = steps;
  steps = 0;
  interrupts();
  return n;
}

bool encoderTakePush() {
  const bool p = pushed;
  pushed = false;
  return p;
}

bool encoderTakeRelease() {
  const bool r = released;
  released = false;
  return r;
}

bool encoderTakeLongPress() {
  const bool p = longPress;
  longPress = false;
  return p;
}

void encoderFlush() {
  noInterrupts();
  encval = 0;
  oldAB &= 0x03;   // keep the low two bits; encoderIsr() needs them next
  interrupts();
  steps = 0;
}

bool encoderPresent() { return began; }

#else

void encoderBegin() {}
void __not_in_flash_func(encoderPoll)() {}
int encoderTakeSteps() { return 0; }
bool encoderTakePush() { return false; }
bool encoderTakeRelease() { return false; }
bool encoderTakeLongPress() { return false; }
void encoderFlush() {}
bool encoderPresent() { return false; }

#endif

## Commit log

2026-09-16 Initial upload
    [C12402012-3.stp, FG0H104ZF.step, PAL-sign.kicad_pcb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]
2026-09-17 Update with ML2032 battery
    [PAL-sign.kicad_pcb, PAL-sign.kicad_sch, bom.csv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]
2026-09-17 Update connector labels
    [PAL-sign.kicad_pcb]
2026-09-17 README: front panel pinout and a PCM audio section
    The screen (ST7789P3, 76 x 284) and rotary encoder with their GPIO
    assignments, and a new section on the optional PCM audio: the two
    cards, the four Ham PCM quality modes, the Sony/EIAJ compatibility,
    automatic hiding without an ADC, and the I2S pinout with the PCM1808
    in master mode.
2026-09-17 Small hardware update
    [PAL-sign.kicad_pcb, PAL-sign.kicad_sch, bom.csv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]
2026-09-18 Update PSU, so USB powering works too
    [PAL-sign.kicad_pcb, bom.csv, designators.csv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]
2026-09-22 PM5644: blink the reference bars from the two PAL phase frames
    The PM5644 G00 and G924 EPROMs each store two PAL phase frames that are
    identical except for the two chroma reference bars flanking the centre
    circle: their chroma is inverted 180 degrees, the luma is untouched. The
    firmware now reproduces that by inverting the bars' chroma on alternate
    frames at 25 Hz, locked to the ADV7391's own 8-field counter (0xBB), so
    the PAL delay-line reference bars blink like the original generator.
    The bar columns and the flip come straight from decoding the raw EPROMs
    (G00 via the 3-byte decoder, G924 via the 2-byte 20 MHz decoder), not from
    guesswork. A per-card flag XORs the flip with the analogue l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
2026-09-22 video: hoist the phase-bar table into locals, fix stale comments
    The inversion loop in videoBuildLine() reloaded the PhasePairRange table
    pointer and each range's first/last on every pair, because the byte
    stores to the row buffer could alias the Pattern as far as the compiler
    knows. Hoisting them into locals drops three of the five loads per pair
    in this RAM hot path.
    Also corrects the comments left behind by the G924 decode: the bars of
    both G00 and G924 carry the +-V alternation in the pixel data, so
    phaseBarsLineComp is true for both rather than "solid" for G924; and the
    phase frame is set from the encoder's field counter by
    videoSetPhaseFrame(), not toggled by a videoTogglePhaseFrame()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
2026-09-23 Multiburst: full-field PAL multiburst with real black and white references
    Replace the computed card: a black (0 V) and a white (0.7 V) reference
    bar, then six full-amplitude bursts on a 50% pedestal at
    0.5/1.5/2.5/3.5/4.5/5.5 MHz, the set bench generators show. Each burst
    spans a whole number of cycles so it starts and ends at pedestal level;
    bar edges are sin-squared shaped. The inserted ITS line 18 is unchanged.
    Tables regenerated by tools/convert_rom_pattern.py.
2026-09-23 Hardware: series inductor for the DAC HF compensation
    Add L3 (4.7 uH) and L4 (1.5 uH), both 0805, in series with R15: 6.2 uH
    in total, chosen from measurements (4.7+2.2 was too high, 4.7+1.0 too
    low). The two existing 1008 coils move to L5/L6. Gerbers, BOM,
    positions, netlist and schematic PDF regenerated.
2026-10-10 TV clock card, and PM5644 phase frames without the line-parity flip
    PM5644: the reference bars are anti-PAL (PM5644 manual 3.8.2:
    non-alternating R-Y, line-alternating B-Y). Inverting them per frame
    only keeps that, so a delay-line decoder shows them grey; the extra XOR
    with the line parity turned them into plain PAL colour that flickered
    on a TV. phaseBarsLineComp removed. The encoder's field count (0xBB) is
    now read only for a card with phase bars, not every frame for all.
    TV clock (card 37): a full-picture analogue clock after the depips.nl
    "TV Klok", left aligned, solid centre dot and longer hand tails. Drawn
    a second ahead, a row at a time in the producer's spare time
    (Pattern::backgro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
2026-10-10 PC tool: TV clock options, all previews follow a text change, wider window
    A change of the first or second text only re-checked the card on
    screen, so every other kept picture kept the old text until a save and
    a reselect. Now every card's checksum is asked again, one per tick, and
    any card that moved is marked out of date; only the card on screen is
    fetched at once, since a fetch shows that card on the board.
    TV clock (own=7): text position top/bottom right, clock and background
    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
2026-10-11 Hardware: PCB update and the fabrication output (BOM, positions, Gerber zip)
2026-10-11 Transparent ticker on photographs, smoothed ticker glyphs, PM5644 frames from the EPROM, BATC Legacy and BBC Micro cards
    video: core1 copies a photograph's rows into the ring ahead of core0 (prefill), which leaves core0 45% idle on a photo instead of 3%; two blank rows instead of four; the producer hooks back on when i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
    ticker: the transparent band in Inter or Doto is laid on by core1 from a per-picture overlay frame; the glyphs are vertically [1,2,1] filtered against interlace twitter, rleDarkenRow blends by covera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

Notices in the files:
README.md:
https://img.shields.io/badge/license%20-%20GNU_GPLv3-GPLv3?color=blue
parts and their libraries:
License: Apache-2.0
